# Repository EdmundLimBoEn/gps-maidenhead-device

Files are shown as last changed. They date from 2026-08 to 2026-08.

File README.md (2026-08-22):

# Maidenhead Pocket Locator

Open hardware and software for a compact GNSS-powered six-character Maidenhead
locator. The product requirements and validation gates live in [PLAN.md](PLAN.md).

## Current status

The development source tree covers RP2040 firmware and host tests, a
Tk/serial configurator with profiles and UF2 recovery, KiCad engineering sources
and manufacturing workflow, a parametric enclosure with printable exports, and
assembly/validation documentation.

This is **not yet a physically validated product release**. Ordering and public
distribution remain gated on the frozen BOM/quote, reviewed manufacturing exports,
prototype bring-up, and measured acceptance evidence listed in
[the release checklist](docs/manufacturing/RELEASE_CHECKLIST.md) and
[evidence index](docs/testing/TEST_EVIDENCE.md). No claim is made here that the
weather, battery, GNSS, off-current, thermal, or cost gates have passed.

## Development

```sh
cmake -S firmware -B .build/firmware
cmake --build .build/firmware
ctest --test-dir .build/firmware --output-on-failure

python -m venv .venv
. .venv/bin/activate
python -m pip install -e './configurator[dev]'
pytest configurator/tests
python -m ruff check configurator tools
python -m ruff format --check configurator tools
python -m maidenhead_configurator

bash firmware/tests/pico_stub_compile.sh
python3 hardware/manufacturing/preflight.py
python3 tools/export_enclosure.py
python3 tools/validate_enclosure.py --require-openscad
python3 tools/check_docs.py
python3 tools/release_preflight.py
```

To build an RP2040 UF2, install the Pico SDK and set its location:

```sh
PICO_SDK_PATH=/path/to/pico-sdk \
  cmake -S firmware -B .build/firmware-pico -DPOCKET_LOCATOR_BUILD_RP2040=ON
cmake --build .build/firmware-pico
```

The GUI starts against a simulator by default. A physical device uses
newline-delimited JSON over USB CDC; each configuration write includes a fresh
15-year named-zone transition table. Profiles remain location-free and portable.

## Manufacturing and safety

Do not order or distribute from an arbitrary working tree. Generate artifacts from
a tagged revision, complete [the five-unit order package](docs/manufacturing/ORDER_PACKAGE.md),
and follow the [assembly](docs/assembly/ASSEMBLY.md) and
[test procedures](docs/testing/TEST_PROCEDURES.md).

The [mechanical interface contract](enclosure/INTERFACES.md) and
[cost research snapshot](docs/manufacturing/COST_RESEARCH.md) make the remaining
fit and landed-cost unknowns explicit. Neither is a manufacturing sign-off.

Use only the released protected LiPo and charger configuration. The device is not
an emergency locator, navigation instrument, tracker, or immersion-rated product.
Do not charge it while wet or leave it charging in a hot vehicle.

## Licensing

Firmware and configurator code are GPL-3.0-or-later. Hardware and mechanical
sources are CERN-OHL-S-2.0. Documentation is CC-BY-SA-4.0. See [LICENSES](LICENSES/README.md).

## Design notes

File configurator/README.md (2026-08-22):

# Configurator

Requires Python 3.11 or newer, Tkinter, and a data-capable USB cable. Install the
project and start the simulated-device prototype with:

```sh
python -m pip install -e .
python -m maidenhead_configurator
```

Some Linux distributions package Tkinter separately (commonly `python3-tk`). The
Windows install automatically includes the `tzdata` package used by `zoneinfo`.
The configurator never derives a time zone from device coordinates; it sends
transitions for the IANA zone selected by the user.

Profiles are versioned JSON. They intentionally omit coordinates, transient GNSS
diagnostics, and the generated time-zone table. Applying a profile or pressing
**Validate and apply** regenerates and sends a compact 15-year transition table
from the host's current IANA database. The supplied
`profiles/factory-default.json` is a portable starting profile.

For a physical device, click **Refresh USB**, select the RP2040 CDC port, and
click **Connect**. The Device screen reports firmware, hardware, configuration
health, and non-persistent diagnostics. If discovery finds nothing, verify that
the cable carries data and that local serial-port permissions allow access.

Normal firmware installation validates the RP2040 UF2, requires a profile
backup, enters ROM BOOTSEL, copies without unsupported filesystem metadata, and
waits for the boot volume to disappear before reconnecting. If application
firmware cannot start, use **Install using BOOTSEL recovery…** after attaching
the device with its internal BOOTSEL control held. ROM volumes are recognized
by their `RPI-RP2` name or `INFO_UF2.TXT`, including Windows drive roots.

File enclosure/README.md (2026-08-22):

# Enclosure engineering source

The parametric OpenSCAD design has an 88 × 44 mm front profile and a calculated
34.5 mm assembled depth. Automated checks confirm those source/export dimensions;
they do not prove component fit, sealing, print tolerance, or RF performance.

The 1.5 mm shell provides 2 mm nominal edge clearance around the current
81 × 37 mm engineering PCB. A 3 mm mating flange provides a real 1 × 0.7 mm
continuous seal groove for nominal 1 mm silicone cord (30% calculated compression)
while retaining 0.5 mm PCB insertion clearance per side.
The lid has a 71 × 25 × 1.1 mm window recess and a
66 × 16 mm through-aperture, leaving a 2.5/4.5 mm continuous seal land. The source also
contains reinforced hard-stop lands, recessed boot apertures, USB plug,
battery rails, antenna frame, and heat-set-insert bosses.

Connector, button, LCD mounting, board retention, antenna orientation, and cable
interfaces remain release-blocking until the exact purchased parts and a shared
datum model pass [the interface contract](INTERFACES.md). The generated shape is
an engineering fit-check, not a production-ready weather-resistant enclosure.

Print structural parts in PETG or ASA, not PLA. Print button boots and the USB
plug in a UV-resistant flexible material. Use a 1 mm clear polycarbonate window
cut to 71 × 25 mm and continuously seal it to the recessed land.

```sh
python3 ../tools/export_enclosure.py
python3 ../tools/validate_enclosure.py --require-openscad
(cd exports && sha256sum -c SHA256SUMS)
```

Before releasing a print, confirm the selected LCD, cell, PCB, coax bend radius,
window, gasket cord, tactile switches, and USB connector against physical samples.
The current battery rails locate a fit dummy but are not a released positive
retainer; that feature remains blocked on the exact cell and Z stack.
After any parameter/source change, regenerate all exports and their checksum file.

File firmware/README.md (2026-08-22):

# Pocket Locator firmware

The firmware uses one C++ core for native tests and the RP2040 UF2. Hardware
code is deliberately isolated under `src/{board,display,gnss,storage,device}`;
the Maidenhead, NMEA, session, layout, configuration validation, and protocol
modules remain host-testable.

## Native tests

```sh
cmake -S firmware -B build/firmware-host
cmake --build build/firmware-host
ctest --test-dir build/firmware-host --output-on-failure
```

## Build a UF2

Install the Raspberry Pi Pico SDK, then either export `PICO_SDK_PATH` or pass
it to CMake.

```sh
cmake -S firmware -B build/rp2040 \
  -DPOCKET_LOCATOR_BUILD_HOST_TESTS=OFF \
  -DPOCKET_LOCATOR_BUILD_RP2040=ON \
  -DPICO_SDK_PATH=/path/to/pico-sdk
cmake --build build/rp2040
```

The resulting `pocket_locator_rp2040.uf2` is an RP2040 ROM-BOOTSEL image.
The application command `reboot_to_bootloader` uses `reset_usb_boot`; the
internal physical BOOTSEL switch remains the recovery mechanism if firmware
does not start.

## Rev-A electrical contract

`include/pocket_locator/board/pins.hpp` is the single source of MCU pin
assignments. The current pin map is deliberately named, not inferred from a
schematic, so production routing must be checked against it before releasing a
PCB revision.

| Function | GPIO | Notes |
| --- | ---: | --- |
| LOCATE / OFF | 2 / 3 | Active-low switches using internal pull-ups and 25 ms polling debounce |
| POWER_HOLD | 4 | High holds the system latch; firmware releases it on shutdown |
| LCD 5 V enable | 5 | Active-high TPS61023 enable; remains low in USB idle |
| LCD RS, E, D4–D7 | 6–11 | 3.3 V outputs into the SN74LVC8T245PWR A-side; LCD R/W is grounded |
| LCD backlight | 12 | PWM into the logic-level backlight MOSFET |
| GP-02 UART TX/RX | 16 / 17 | UART0 at 9,600 8N1; RX is receiver output |
| GNSS enable | 18 | Active-high switched receiver enable; firmware waits 5 ms for the rail before assigning UART pins |
| Battery divider | 26 / ADC0 | 100 kΩ / 100 kΩ (2:1) with 100 nF; firmware waits 30 ms (6× the 5 ms RC constant) before sampling |
| USB VBUS / charger status | 19 / 20 | VBUS active-high; USB device pull-up is enabled only while VBUS is present; charger status active-low/open-drain |
| Battery-divider enable | 21 | Active-high only for the ADC sampling window |

The selected power circuit must permit USB VBUS to sustain the MCU after
`POWER_HOLD` is released. `POWER_HOLD` must not be connected to any reset or
watchdog output. The GP-02 is explicitly disabled in USB idle, and no GNSS
coordinates are written to flash.

On a battery start, `POWER_HOLD` remains low until the software has observed
the continuous LOCATE hold for one second. A LOCATE already held while the MCU
comes out of reset is timestamped at boot (`0 ms`), so the accepted-session
deadlines retain the physical press edge as closely as the latch power-up
latency permits; they are never rebased to the end of debounce or hold checks.

## Flash configuration reservation

`FlashConfigStore` uses the final two physical flash sectors (8 KiB) on the
2 MiB production flash: inactive sector erase/write, XIP read-back/CRC
verification, then a one-way commit marker. The application image must remain
below that reserved tail. Check the generated `.elf`/map in release CI and do
not change the configured flash size without revisiting this reservation.

The linker asserts that the image ends before the reserved region. A power loss
at any write phase leaves the previous committed record valid. Factory reset
commits defaults through the same inactive-slot transaction; it never erases
application firmware or destroys the prior record before defaults verify.

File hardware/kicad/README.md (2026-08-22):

# Hardware design source

SPDX-License-Identifier: CERN-OHL-S-2.0

This directory contains the revision-A *engineering* KiCad source for the
Maidenhead Pocket Locator.  It is deliberately a source-controlled design,
not by itself a claim that an assembled product has been validated: the selected
LCD, patch antenna, cell and enclosure still require physical fit checks. No RF,
power, charger or thermal measurement has been performed on assembled hardware.

`design.yaml` is a review summary of the electrical architecture and constraints;
the component/pin contract is embedded in `generate_kicad.py`. The generator
writes the legacy schematic and cache while preserving the authoritative routed
PCB. Passing `--force-placement` explicitly replaces the PCB with its
deterministic unrouted placement. The source set contains:

* `maidenhead-pocket-locator.sch` — deterministic legacy Eeschema source;
* `maidenhead-pocket-locator.kicad_sch` — the committed modern KiCad source,
  synchronized from the legacy source with KiCad and used for PDF/netlist exports;
* `maidenhead-pocket-locator.kicad_pcb` — the authoritative routed 4-layer,
  81 x 37 mm board with edge connectors, test points and controlled RF/USB
  net classes. The default manufacturing preflight requires zero DRC errors,
  zero unconnected items, filled inner planes, no signal tracks on In1, and
  only the length-bounded `LCD_RS_3V3`, `LOCATE_N`, `QSPI_SCLK`, and
  `QSPI_SD2` crossovers on In2.

The generated board is useful for electrical/mechanical review and routing
iteration. It must not be sent to a fabricator until the
release checklist passes.  `../manufacturing/export.sh` runs the KiCad CLI
exports and DRC when KiCad is installed.

## Regenerate and inspect

```sh
python3 hardware/kicad/generate_kicad.py
# After an intentional electrical edit, open the legacy .sch in the pinned KiCad
# version, save the converted modern .kicad_sch, and run preflight to compare them.
# Only when intentionally restarting layout:
python3 hardware/kicad/generate_kicad.py --force-placement
python3 hardware/manufacturing/preflight.py --source-only
python3 hardware/manufacturing/preflight.py
kicad hardware/kicad/maidenhead-pocket-locator.kicad_pro
```

The source-only command is a diagnostic aid. CI and manufacturing exports use
the strict default command; it must pass before manufacturing exports are
accepted.

The board datum is the lower-left outside corner.  LCD/window centre is
`(40.5, 18.5)`.  The antenna is an enclosure-mounted patch, not a PCB
component; its 50-ohm route ends at J4.  Keep the top-wall patch projection
clear of copper and parts as documented in `../RF_AND_LAYOUT.md`.

The controlled stack is F.Cu signal/power, In1 uninterrupted GND reference,
In2 predominantly 3V3 power distribution, and B.Cu signal/GND. In2 carries only
the under-7 mm LCD RS, under-4 mm LOCATE, and under-6 mm QSPI SCLK/SD2
crossovers allowlisted by preflight. USB and GNSS RF stay on outer copper over
In1; the short QSPI inner runs also reference the uninterrupted In1 plane. Obtain
the fabricator's impedance calculation before release; nominal
trace widths in the source are starting values, not a substitute for a coupon.
Ordinary logic uses 0.15 mm traces and 0.50/0.20 mm through-vias. Dense QSPI
fanout uses 0.10 mm traces and local 0.46/0.20 mm standard through-vias; confirm
the 0.13 mm annular ring with the selected fabricator. The edge rule
is 0.20 mm for the unavoidable short escapes at J1, SW1 and SW2; confirm both
capabilities in the selected board quote.

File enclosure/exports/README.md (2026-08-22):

# Generated enclosure exports

Generate STL files from `../source/enclosure.scad` with the commands in the
enclosure README. Generated meshes are revision artifacts; the OpenSCAD source
and its parameters remain authoritative.

`SHA256SUMS` covers the four printable meshes, window-cut profile, and generated
assembly preview. Run
`python3 ../../tools/validate_enclosure.py --require-openscad` to verify dimensions,
mesh validity, and agreement with freshly rendered source. `assembly.png` remains
an orientation preview and is not dimensional evidence.

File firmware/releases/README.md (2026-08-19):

# Firmware release artifacts

`pocket_locator_rp2040.uf2` is built from the repository firmware source with
the Raspberry Pi Pico SDK. Rebuild it with the commands in `firmware/README.md`
and verify its RP2040 family identifier before distribution.

Verify the tracked artifact with `sha256sum -c firmware/releases/SHA256SUMS`
from the repository root.

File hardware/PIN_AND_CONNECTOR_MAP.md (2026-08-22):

# Pin and connector map — Revision A

SPDX-License-Identifier: CC-BY-SA-4.0

This table is the electrical contract between the board and
`firmware/include/pocket_locator/board/pins.hpp`. A PCB release must reconcile
it against the *purchased* GP-02, LCD and charger datasheets; a named net is
not evidence that a symbol pin is correct.

## RP2040 assignment

| RP2040 pin/function | Net | Connected hardware | Electrical notes |
|---|---|---|---|
| GPIO2 | `LOCATE_N` | SW1 | Active low; local pull-up to 3V3; the same actuator starts the hardware latch through an isolated transistor path. |
| GPIO3 | `OFF_N` | SW2 | Active low; local pull-up to 3V3. |
| GPIO4 | `POWER_HOLD` | Q2 gate/control | Assert high only after one-second LOCATE validation. Must default low/Hi-Z at reset. |
| GPIO5 | `LCD_POWER_EN` | U5 EN | Active high; USB idle keeps the 5 V LCD rail disconnected. |
| GPIO6 | `LCD_RS_3V3` | U6 A0 | U6 B0 -> J3 pin 4. |
| GPIO7 | `LCD_E_3V3` | U6 A1 | U6 B1 -> J3 pin 6. |
| GPIO8 | `LCD_D4_3V3` | U6 A2 | U6 B2 -> J3 pin 11. |
| GPIO9 | `LCD_D5_3V3` | U6 A3 | U6 B3 -> J3 pin 12. |
| GPIO10 | `LCD_D6_3V3` | U6 A4 | U6 B4 -> J3 pin 13. |
| GPIO11 | `LCD_D7_3V3` | U6 A5 | U6 B5 -> J3 pin 14. |
| GPIO12 / PWM | `BL_PWM` | Q3 gate | Q3 is LCD backlight low-side switch; do not drive LCD logic supply with PWM. |
| GPIO16 / UART0 TX | `GNSS_RX` | U7 UART input | MCU output to receiver input. |
| GPIO17 / UART0 RX | `GNSS_TX` | U7 UART output | Receiver output to MCU input. |
| GPIO18 | `GNSS_EN` | U7 enable/load switch | Default low; does not supply GNSS backup power during shutdown. |
| GPIO19 | `VBUS_PRESENT` | VBUS sense divider | Series/diode isolated: VBUS must never power 3V3 through this pin. |
| GPIO20 | `CHG_N` | U3 CHG output | Open drain/active low; RCHGPU1 is the explicit 100 kΩ logic pull-up, in parallel with the separately current-limited RCHG1/LED indicator branch. |
| GPIO21 | `BAT_SENSE_EN` | Q5/Q4 divider switch | Pulse high, wait for the 100 nF ADC node to settle, sample, then return low. |
| GPIO26 / ADC0 | `BAT_ADC` | switched divider | Q4 isolates BAT whenever GPIO21 is low or 3V3 is absent; calibrate before setting battery icon thresholds. |
| QSPI CSn (ROM BOOTSEL) | `BOOTSEL_N` | SW3 to GND | Physical recovery switch only. Never connect to ordinary GPIO or LCD. |
| RUN | `RUN_N` | SW4 to GND / TP | Reset; pull-up and capacitor must follow RP2040 reference circuit. |
| XIN / XOUT | `XIN` / `XOUT` | X1 ABM8-272-T3 | 15 pF C0G loads; XOUT passes through 1 kΩ RXTAL1 to `XOUT_XTAL` to limit crystal drive. |
| SWDIO / SWCLK | `SWDIO`, `SWCLK` | TP pads | Test pads, no production debug connector required. |

Unused GPIOs are not routed to external connectors. Keep their reset pulls as
recommended by the RP2040 hardware design guide.

## External connectors and LCD header

| Connector / pin | Net | Direction / purpose |
|---|---|---|
| J1 USB-C A4/A9/B4/B9 | `VBUS_RAW` | 5 V receptacle input; F1 creates protected `VBUS` for charger and sensing. No PD source capability. |
| J1 USB-C A6/B6 | `USB_DP_CONN` | USB 2.0 D+ into D1; D1 output and RUSB1 create `USB_DP` at RP2040. |
| J1 USB-C A7/B7 | `USB_DM_CONN` | USB 2.0 D− into D1; D1 output and RUSB2 create `USB_DM` at RP2040. |
| J1 CC1, CC2 | `CC1`, `CC2` | Independent 5.1 kΩ Rd to GND. |
| J1 shield and GND pins | `GND` | Tie to ground plane at connector; final EMI treatment requires review. |
| J2 pin 1 | `BAT` | Protected cell positive to BQ24074 BAT. BQ24074 OUT, rather than the raw cell, creates `SYS_RAW`. |
| J2 pin 2 | `CHG_TS` | Cell thermistor to BQ24074 TS; TH1 is alternative only. |
| J2 pin 3 | `GND` | Cell return. |
| J3 pin 1 / 2 | `GND` / `5V_LCD` | LCD logic supply. |
| J3 pin 3 | `LCD_VO` | Contrast potentiometer/divider, 5 V-safe. |
| J3 pin 4 / 6 | `LCD_RS` / `LCD_E` | From U6 B0/B1. |
| J3 pin 5 | `GND` | LCD R/W permanently low. |
| J3 pins 7–10 | `GND` | LCD D0–D3 unused in 4-bit mode. |
| J3 pins 11–14 | `LCD_D4`–`LCD_D7` | From U6 B2–B5. |
| J3 pin 15 / 16 | `LCD_BL_A` / `LCD_BL_K` | Positive through verified current limit; Q3 PWM low side. |
| J4 centre / shell | `GNSS_RF_50R` / `GND` | u.FL to enclosure patch; centre trace has 50-ohm grounded-coplanar target. |

## Required test points

`VBUS`, `BAT`, `SYS_RAW`, `3V3`, `5V_LCD`, `GND`, `POWER_HOLD`, `GNSS_TX`,
`GNSS_RX`, `SWDIO`, `SWCLK`, `RUN_N`, and `BOOTSEL_N` shall be present as
labelled, probe-accessible pads. Test pad placement must preserve the GNSS
RF keep-out and never turn a debug probe ground lead into the RF return path.

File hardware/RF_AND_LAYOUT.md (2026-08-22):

# RF, placement, and routing constraints — Revision A

SPDX-License-Identifier: CC-BY-SA-4.0

The GP-02 to patch assembly is the principal reception risk. This document
defines constraints for the design; it does not certify antenna performance.
If the purchased GP-02 requires a different matching topology, its datasheet
supersedes this document and the schematic/PCB must be revised together.

## GNSS path

1. U7 RF pin to J4 is a continuous 50-ohm grounded coplanar waveguide on the
   outer layer. Calculate width, clearance, and via fence pitch from the
   *ordered* JLCPCB stack-up; do not copy a generic 50-ohm width.
2. Do not place a series DC-block or matching component unless required by the
   purchased receiver/patch data. Preserve a footprint land pattern for an
   optional 0402 series component and a shunt-to-ground component only when
   the actual reference circuit permits it.
3. Keep this route as short as practical, with no stubs, neck-downs, vias, or
   90-degree corners. Ground vias flank the line at a pitch no greater than
   one-tenth of the effective wavelength in board material; refine after the
   selected stack-up is known.
4. Keep the u.FL launch and its shell vias continuous with the RF ground. The
   coax may not be sharply folded, trapped under a screw boss, or routed across
   the 5V inductor, USB pair, LCD flex/header, or RP2040 crystal.
5. The 25 x 25 mm patch is mounted ceramic-face upward below the enclosure top
   wall. No battery, LCD PCB, screw, metallic paint, copper, or other conductor
   is allowed directly above it. Its ground-plane requirement is a purchased
   antenna-data-sheet gate, not an assumed rectangle of copper.

## Noise separation and plane strategy

- Use a solid, uninterrupted B.Cu ground plane except for approved RF
  clearances. Route low-speed signals on F.Cu where possible; never slit the
  return path beneath USB D+/D− or the RF line.
- Put U5/L1/C11 together on the side opposite U7/J4. The switch node is the
  smallest possible copper island and is surrounded by a ground return. Do not
  pour copper under the inductor unless its datasheet allows it.
- Keep the RP2040 crystal and its load capacitors adjacent to U1, with no USB,
  PWM, boost, or RF trace below/through the crystal keep-out.
- Put D1 at J1 before the USB pair enters the board. Route D+/D− as a short,
  matched differential pair over continuous ground, avoiding stubs at any
  optional series parts.
- PWM backlight current returns directly to the 5V boost output capacitor,
  not through the GNSS ground region. Verify the effect with satellite tests
  at backlight-off, dim, full, USB-active, and LCD-update conditions.

## Placement and board mechanics

The nominal four-layer PCB is 81 x 37 mm inside an approximately 88 x 44 mm front
enclosure. J1 is centred on the left wall; the LCD is rear-mounted at the
window datum; U7/J4 occupy the upper-right RF zone; power conversion occupies
the lower-left/centre away from RF. The final enclosure source controls exact
boss, gasket, window, button, and antenna locations.

Before ordering, import the enclosure datum model and verify these minimum
checks: board-to-wall clearance, USB shell/cap clearance, LCD glass/window
gap, battery pouch and lead bend radius, patch clearance, button travel,
light-pipe alignment, screw-boss keep-outs, and test-pad access with a probe.

## Four-layer release rules

- Board edge, holes, PCB thickness, and the explicit 0.20 mm copper-to-edge
  minimum are confirmed against the fabricator capability selected for the
  quote. The 0.20 mm rule is required by the short escapes from the three
  edge-mounted parts (J1, SW1 and SW2); do not order from a process with a
  larger finished-copper edge requirement.
- All component footprints are from a reviewed local library or vendor drawing
  and include pin-1/polarity markings. Never fabricate from the placeholder
  outline blocks in the early generated board.
- Assign net classes before routing: RF controlled impedance, USB differential
  pair, battery/charger high current, LCD boost/backlight, and ordinary logic.
- Ordinary logic uses 0.15 mm traces and 0.50/0.20 mm finished through-vias;
  the selected four-layer process must explicitly support those dimensions.
  USB, RF, and power keep their dedicated net-class geometry and are not
  reduced to the ordinary-logic values to escape congestion.
- Run ERC and DRC with zero unreviewed errors, inspect Gerbers in an independent
  viewer, and use the fabrication checklist in `manufacturing/`.

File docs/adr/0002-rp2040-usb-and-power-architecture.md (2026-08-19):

# ADR-0002: Use RP2040, USB-C, power-path charging, and hardware shutdown

- Status: accepted
- Date: 2026-08-19

## Context

The device needs cross-platform USB configuration, end-user firmware updates, operation while charging, eight-hour outing endurance, and enough retained charge for one check after a year of storage. Custom firmware is explicitly allowed.

## Decision

Use an RP2040 with native USB and external QSPI flash. USB-C carries 5 V charging and USB 2.0 data. Use a BQ24074-class power-path charger and a low-leak hardware soft latch that physically removes switched system power. USB VBUS may keep the MCU in a dark, GNSS-off configuration state.

Normal and recovery updates use RP2040 ROM BOOTSEL and UF2. Normal firmware can reboot itself into BOOTSEL. If application firmware cannot run, removing the rear cover and holding a labelled internal BOOTSEL switch while attaching USB forces recovery without electrically multiplexing a runtime button onto QSPI flash control.

## Consequences

- Updates are recoverable without a debug probe.
- Shutdown current depends mainly on charger, load-switch, and protection leakage rather than MCU sleep quality.
- The PCB needs additional flash, USB protection, latch logic, and careful power sequencing.
- Unsigned custom firmware can replace all application behavior; the GUI must warn and back up configuration first.

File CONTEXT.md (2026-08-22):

# Domain Glossary

## Product terms

**Maidenhead Pocket Locator**  
The complete portable device described in `PLAN.md`.

**Locator**  
The six-character Maidenhead representation calculated from the current WGS-84 position, for example `OJ11XH`. Use “six-character,” not “six-digit,” because four positions are letters.

**Current fix**  
A receiver-declared valid GNSS position obtained during the present check session. A previously acquired position is never treated as current.

**Check session**  
The interval beginning at the initial `LOCATE` button-down edge of a subsequently accepted one-second hold, and ending when `OFF`, the shutdown deadline, or a failure releases the hardware power hold.

**Single-fix mode**  
A check session that stops active GNSS tracking after the first valid position is displayed.

**Tracking mode**  
A check session that continues processing GNSS fixes and considers a display update every five seconds.

**Grid stabilization**  
The rule requiring two consecutive valid fixes in the same new locator before the displayed locator changes.

**Acquisition timeout**  
Maximum duration from the initial button-down edge of an accepted `LOCATE` hold to a valid GNSS fix. Factory default: 120 seconds.

**Dim deadline**  
Time from the initial button-down edge of an accepted `LOCATE` hold at which the backlight changes to configured dim brightness. Factory default: 60 seconds.

**Shutdown deadline**  
Time from the initial button-down edge of an accepted `LOCATE` hold at which the hardware power hold is released. Factory default: 120 seconds, except for the three-second terminal `NO GPS` message.

**Factory settings**  
The safe configuration restored by a five-second two-button hold. The factory named time zone is `Asia/Singapore`.

## Hardware terms

**Power hold**  
The MCU signal that keeps the switched system rails enabled after the physical `LOCATE` press starts the device.

**Hard shutdown**  
The state in which switched rails for MCU, GNSS, LCD, and sensing are physically removed rather than relying only on MCU sleep.

**Power path**  
Charger behavior that independently powers the system and charges the cell, allowing normal operation while USB is connected without corrupting charge termination.

**Internal patch**  
The passive ceramic GNSS antenna mounted under the enclosure's top wall and connected to the GP-02 by short coax and u.FL/I-PEX.

**Front profile**  
The enclosure width and height seen from the LCD face. The frozen engineering envelope is 88 × 44 mm, with total depth limited to 35 mm.

**Weather goal**  
Survival of drizzle, dust, and incidental sand exposure. It is not an IP rating and does not include immersion.

## Software terms

**Display builder**  
The configurator screen where battery, time, date, separators, and static-text fields are arranged with a live 16-character preview.

**Configuration profile**  
A versioned, human-readable JSON representation of user settings that can be saved and applied to multiple devices. It never contains position history.

**Named zone**  
An IANA time-zone identifier such as `Asia/Singapore` or `America/New_York`. V1 receives its future offset transitions from the host configurator; it does not infer the zone from coordinates.

**Normal update**  
A GUI-driven firmware update that asks running firmware to enter RP2040 ROM BOOTSEL and then installs a selected UF2.

**Recovery update**  
A firmware update entered by opening the rear cover and holding the internal `BOOTSEL` control while connecting USB, independent of application firmware.

**V1**  
The first public hardware, firmware, enclosure, and configurator release that passes the acceptance criteria in `PLAN.md`.

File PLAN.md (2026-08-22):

# Maidenhead Pocket Locator — Build Plan

Status: development sources and automated electrical/layout checks are complete and clean; manufacturing remains blocked on exact-part Z-stack and physical-overlay validation, exact-part sourcing, a landed quote, prototypes, and measured acceptance evidence
Target batch: 5–20 devices  
Hard landed-cost target: **US$30 or less for every unit, including the first five**  
Licensing goal: reciprocal open source

## 1. Product definition

Build a compact, battery-powered amateur-radio companion that obtains its current position from GNSS and displays the corresponding six-character Maidenhead locator on a blue-backlit 16×2 character LCD.

The device is intended for desks, portable radio outings, and use in occupied vehicles. It should feel like a useful radio tool and a fun object to give to other operators. It is not a navigation device, emergency beacon, location logger, or formally rated waterproof product.

### Default display

```text
GRID: OJ11XH
▰ 14:35 19/08
```

The battery glyph is illustrative. The firmware will use one of the LCD's custom-character slots for a four-level battery icon.

### Primary interaction

1. Hold `LOCATE` for one second.
2. The device powers up and immediately shows `ACQUIRING GPS` rather than a cached grid.
3. On a valid fix, it calculates and displays the six-character locator and flashes the backlight briefly.
4. By default, the backlight dims 60 seconds after the original `LOCATE` button-down edge.
5. By default, the device shuts down 120 seconds after that same button-down edge.
6. Holding `OFF` for one second shuts it down early.
7. Holding both buttons for five seconds restores factory settings after an on-screen countdown.

Once the one-second hold is accepted, all timers are backdated to the initial `LOCATE` button-down edge, including time spent validating the hold and acquiring GNSS. If the default two-minute acquisition timeout expires without a fix, show `NO GPS` for three seconds and shut down; this terminal message is the only default exception to the 120-second power-off deadline.

### Configuration modes

The Python configurator selects one of two GNSS behaviors:

- `single_fix`: acquire one valid position for the session, display it, and stop active GNSS tracking.
- `tracking`: continue processing fixes and update the locator every five seconds until shutdown.

In tracking mode, a new locator must appear in two consecutive valid fixes before replacing the displayed locator. This prevents grid flicker near a subsquare boundary.

### Non-goals for V1

- No location history or logging; coordinates are discarded at shutdown.
- No stale-location fallback.
- No external GNSS antenna connector.
- No automatic geographic time-zone detection.
- No Wi-Fi, Bluetooth, mobile app, buzzer, lanyard, or belt clip.
- No immersion rating or untested IP claim.
- No on-device settings menus.

## 2. Acceptance criteria

V1 is complete only when all of the following pass:

| Area | Acceptance criterion |
|---|---|
| Locator | Correct uppercase six-character Maidenhead output from WGS-84 latitude/longitude, including boundary and antimeridian tests |
| Cold fix | At least 9 of 10 open-sky cold-start trials produce a valid grid within the configured default two-minute timeout |
| Stability | A new grid appears only after two consecutive valid fixes agree |
| Battery outing | Survives an eight-hour test with four full two-minute checks per hour and retains enough charge for one additional check |
| Stored unit | Electronics shutdown current is at most 10 µA at 25 °C; after realistic one-year cell self-discharge, the design budget still allows at least one location check |
| Controls | Each button requires a deliberate one-second hold; bag pressure and short taps do not latch the device on |
| USB | Charging, configuration, and normal location operation work while connected |
| Firmware recovery | An interrupted or invalid update can be recovered through the internal RP2040 ROM BOOTSEL control without a debugger |
| Configuration | Settings persist across shutdown, reject corruption, and can be saved/restored as profiles |
| Weather goal | Passes the drizzle and sand procedures in section 8 with no internal ingress or control failure |
| Thermal | Operates at 40 °C ambient and inhibits charging when the battery sensor is too warm |
| Mechanical | Front profile remains approximately LCD-sized (engineering source: 88 × 44 mm); total depth does not exceed 35 mm |
| Cost | Quoted landed cost is no more than US$30 per finished unit when ordering the first five |

The locator definition and test vectors should follow the ADIF WGS-84 encoding: positions 1–2 use `A–R`, 3–4 use `0–9`, and 5–6 use `A–X`. See the [ADIF Maidenhead definition](https://adif.org.uk/315/ADIF_315.htm#Maidenhead_Locators).

## 3. Hardware plan

### 3.1 Architecture

```mermaid
flowchart LR
    USB[USB-C] --> CHG[Power-path charger]
    CELL[Protected 1S LiPo] <--> CHG
    CHG --> LATCH[Low-leak load switch / soft latch]
    LOCATE[LOCATE button] --> LATCH
    LATCH --> RAIL3[3.3 V rail]
    LATCH --> BOOST[5 V LCD boost]
    RAIL3 --> MCU[RP2040]
    RAIL3 --> GPS[GP-02 GNSS]
    GPS -->|UART NMEA| MCU
    PATCH[Internal passive patch] -->|short coax + u.FL| GPS
    MCU -->|PWM| BOOST
    MCU --> LEVEL[SN74LVC8T245 level shift]
    LEVEL --> LCD[Blue 1602 LCD]
    OFF[OFF button] --> MCU
    MCU -->|power hold / release| LATCH
```

### 3.2 Candidate parts and rationale

These are design candidates, not permission to order. Freeze exact manufacturer part numbers only after schematic review, stock confirmation, physical layout, and the cost gate.

| Function | V1 candidate | Reason / constraint |
|---|---|---|
| MCU | RP2040 + 2 MB QSPI flash | Low-cost native USB, adequate UART/PWM/ADC, mature C/C++ SDK, and UF2 recovery in immutable ROM. The [RP2040 datasheet](https://datasheets.raspberrypi.com/rp2040/rp2040-datasheet.pdf) documents the USB controller and ROM bootloader. |
| GNSS receiver | Ai-Thinker GP-02 | Cost-down choice; multi-constellation receiver with UART NMEA and passive/active antenna support. Use the [manufacturer specification](https://docs.ai-thinker.com/_media/gp-02_specification.pdf) as the schematic authority. |
| GNSS antenna | Internal passive L1 ceramic patch with short coax and u.FL/I-PEX plug | Allows the patch to mount beneath the top wall and face the sky without enlarging the LCD-like front profile. Final antenna must provide documented dimensions, cable loss, ground requirements, and operating temperature. |
| GNSS fallback | Quectel L86-M33 | Use only if the GP-02 plus remote patch fails reception tests. Its integrated patch is lower RF-integration risk but materially more expensive. |
| LCD | HD44780/ST7066-compatible blue-backlit 16×2 module, nominal 80 × 36 mm | Matches the requested Arduino-kit appearance. Freeze a 5 V part with measured backlight current and published outline drawing. A representative module is up to 13.5 mm thick; see [Winstar WH1602B](https://www.winstar.com.tw/products/lcd-display/character-lcd-display-module/lcd-display-16x2.html). |
| LCD level translation | SN74LVC8T245PWR, write-only 4-bit LCD bus | Its dual rails translate RP2040 3.3 V outputs to the 5 V LCD domain. Strap direction A→B, hold output-enable active, ground unused A inputs, tie LCD `R/W` low, and use fixed command delays. |
| LCD supply | TPS61023 set to 5 V | Efficient boost converter with true disconnect and about 0.1 µA shutdown current. See [TI TPS61023](https://www.ti.com/product/TPS61023). |
| Backlight control | Logic-level MOSFET driven by MCU PWM | Provides normal/dim brightness sliders, success flash, and full backlight cutoff. Verify the selected LCD includes or receives a safe LED current-limiting resistor. |
| Charger / power path | BQ24074 | Supports simultaneous system use and charging, input limiting, thermal regulation, and battery NTC monitoring. See [TI BQ24074](https://www.ti.com/product/BQ24074). Do not replace it with a charger lacking load sharing merely to save cost. |
| Battery | Replaceable protected 1S LiPo, preliminary 1,000 mAh, keyed JST-PH-class connector | Capacity is intentionally provisional. Freeze it after measuring the selected LCD and a complete two-minute session. Use a reputable protected cell; prevent reverse insertion mechanically and electrically. |
| Battery indication | Switched high-value divider into MCU ADC | Four-level icon only. Enable the divider only while measuring; calibrate thresholds against the assembled unit under a known light load. |
| Charge indication | Charger status output to a red LED behind a sealed light pipe | LED is on while charging and off when complete or unplugged. The LCD remains dark merely because USB is attached. |
| USB-C | USB 2.0 device connector with CC resistors, ESD protection, and tethered sealing plug | Must work with USB-A-to-C and C-to-C data cables. USB provides charging, CDC configuration, and firmware update. |
| Buttons | Two side-mounted tactile switches under matching recessed elastomer actuators | Both require a one-second hold. Actuators should feel like a radio PTT rather than exposed PCB buttons. |

### 3.3 Power behavior

Use a hardware soft-latch rather than relying on MCU deep sleep:

- A `LOCATE` press temporarily enables the post-charger system load switch.
- The MCU asserts `POWER_HOLD` only after the press remains valid for one second.
- Releasing `POWER_HOLD` removes power from the MCU, GNSS, LCD boost, level shifter, and sensor divider.
- USB VBUS independently enables the MCU so the configurator is always reachable. USB insertion must not light the LCD or start GNSS by itself.
- While USB is present, `OFF` returns the firmware to USB-idle mode because external power intentionally keeps the configurator alive.
- The charger and cell protection remain connected during shutdown. Their combined battery drain, plus load-switch leakage, must meet the 10 µA electronics target.
- Do not maintain GNSS backup power for a full year; accept a cold start after long storage in exchange for lower drain.
- Add a power-on-reset supervisor if testing shows unreliable latch startup or flash corruption near battery cutoff.

Preliminary charging configuration:

- USB input: 5 V only; no USB Power Delivery negotiation.
- Input limit: 500 mA unless thermal testing supports more.
- Charge current: select after the exact cell is chosen; never exceed its datasheet rating.
- Battery NTC: use the cell's third wire when available, otherwise mount a board thermistor firmly against the cell pouch.
- Charging should stop outside the cell supplier's permitted temperature window; the 40 °C ambient requirement is not permission to charge an overheated cell.

### 3.4 PCB

- Design in KiCad as a four-layer board: F.Cu/B.Cu carry signals, In1 is an
  uninterrupted ground reference, and In2 distributes power with only four
  length-bounded crossovers: LCD RS (under 7 mm), LOCATE (under 4 mm), and
  QSPI SCLK/SD2 (under 6 mm). USB and RF remain on the outer layers. The two-layer
  cost-first attempt was rejected because routing fragmented critical return
  paths for USB and GNSS RF.
- Let JLCPCB assemble all SMD parts, including RP2040, GP-02, charger, converters, USB-C, ESD, and level shifting.
- Keep hand work to the LCD/header, battery plug-in, antenna plug-in, actuator installation, and enclosure assembly.
- Place labelled test points for `VBUS`, `BAT`, charger output, `3V3`, `5V_LCD`, `GND`, `POWER_HOLD`, UART TX/RX, SWDIO, SWCLK, RUN, and BOOTSEL.
- Route the GP-02 RF output to u.FL as a short 50 Ω grounded coplanar trace using JLCPCB's actual stack-up. Add ground stitching vias and obey the receiver and connector keep-outs.
- Keep the GNSS/RF area away from the 5 V boost inductor, LCD edge, USB data pair, and RP2040 crystal.
- Place USB-C, LED light pipe, button switches, LCD header, and battery connector from the CAD assembly—not by schematic convenience.
- Add polarity, pin-1, connector, and button labels to silkscreen.
- Export manufacturing files, schematic PDF, interactive BOM, pick-and-place, and JLC assembly drawings from versioned source.

### 3.5 Enclosure

Target envelope: approximately LCD-sized and **no more than 35 mm deep**. The engineering enclosure is **88 × 44 × 34.5 mm** because the original 85 × 41 mm concept left no physical land for both the 81 × 37 mm PCB and a continuous gasket. Depth absorbs the battery, PCBA, sealing, and antenna orientation.

Construction:

- Two-piece screw-fastened FDM enclosure in PETG or ASA; do not use PLA for the field version.
- Continuous perimeter gasket in a designed compression groove. Use hard stops so screws cannot crush or extrude the gasket.
- Recessed clear polycarbonate LCD window with its own gasket or continuous closed-cell adhesive seal; do not expose the LCD glass directly.
- Matching recessed elastomer button boots or a single molded membrane over the two tactile switches.
- Tethered USB-C port plug and a gasketed/light-pipe charging indicator.
- Internal ceramic patch adhered beneath the top wall, ceramic face toward the sky, with no battery, display PCB, fastener, metallic coating, or copper immediately above it.
- Replaceable battery retained without puncture risk, foam compression on the pouch, or strain on its leads.
- Captive or retained threaded inserts where practical; repeated battery access must not destroy FDM screw holes.
- No lanyard or clip features.

Weather claim: “designed for drizzle, dust, and incidental sand exposure; not for immersion.” A future machined enclosure should preserve the PCB, control, antenna, window, and gasket interfaces.

### 3.6 Cost gate

The following is a target allocation, not a quote. It includes allocated setup and shipping but excludes the builder's labor and borrowed tools, matching the agreed parts-cost definition.

| Cost group | Target per unit |
|---|---:|
| LCD | $2.00–3.50 |
| GP-02 + internal patch/coax | $3.50–5.00 |
| RP2040, flash, clock, USB | $1.75–2.75 |
| Charger, load switch, 3.3 V/5 V power, level shifting, protection, passives | $3.50–5.00 |
| Protected LiPo + connector | $3.00–5.00 |
| PCB and PCBA allocation | $3.00–5.00 |
| Enclosure, window, gasket, actuators, screws, light pipe | $2.50–4.00 |
| Allocated shipping, setup, extended-part, and fixture charges | $2.00–4.00 |
| **Target total** | **$21.25–34.25** |

Because the high estimate exceeds the requirement, cost control is a formal milestone:

1. Prepare the complete five-unit JLCPCB cart and every non-JLC purchase before ordering anything.
2. Include taxes, shipping, setup, assembly, stencil/fixture, spare-part minimums, and enclosure consumables.
3. Divide the total by five finished devices; do not hide unused minimum-quantity parts outside the calculation.
4. If the total exceeds $150, reduce cost and requote. Do not order on the assumption that later units will amortize it.
5. Cost-down order: consolidate JLC basic parts, source LCD/cell/window hardware locally, simplify non-safety mechanical hardware, then compare compatible documented GNSS/antenna parts.
6. Do **not** cost down by removing cell protection, NTC monitoring, power-path/load sharing, USB ESD, the gasket/window, or firmware recovery.

## 4. Firmware plan

### 4.1 Stack and modules

Use the Raspberry Pi Pico C/C++ SDK with CMake. Keep hardware drivers thin and put all conversion, layout, configuration, and state behavior in host-testable C++ modules.

Suggested modules:

```text
firmware/
  app/             state machine and event loop
  board/           pins, clocks, ADC, power hold, boot entry
  gnss/            UART transport, NMEA parsing, fix validity
  maidenhead/      pure WGS-84 coordinate-to-locator conversion
  display/         1602 driver, glyphs, PWM, screen composition
  layout/          validated 16-character field renderer
  time/            GNSS UTC and configured named-zone transitions
  config/          schema, defaults, migration, CRC, atomic storage
  usb/             CDC protocol, diagnostics, bootloader command
  tests/            native and device tests
```

### 4.2 State machine

| State | Entry / behavior | Exit |
|---|---|---|
| `OFF` | Hardware rails absent | `LOCATE` begins enabling power, or USB supplies configuration power |
| `PRESS_CHECK` | Count a continuous one-second `LOCATE` hold; if accepted, use the initial button-down edge as all timer epoch | Short release → power drops; valid hold → `ACQUIRING` |
| `USB_IDLE` | CDC/configuration active; LCD and GNSS off | `LOCATE` → `ACQUIRING`; USB removal → power drops unless held |
| `ACQUIRING` | Show `ACQUIRING GPS`; parse only current live fix data | Valid fix → `DISPLAY_FIX`; timeout → `NO_GPS`; `OFF` → shutdown |
| `DISPLAY_FIX` | Show `GRID: XX00XX`, battery, time/date layout; flash backlight | Single-fix mode stops GNSS; tracking mode continues; dim deadline → `DIMMED` |
| `DIMMED` | Use configured dim PWM; continue selected GNSS mode | Shutdown deadline or `OFF` → shutdown; valid tracking fix may update grid |
| `NO_GPS` | Show failure for three seconds | Release power hold |
| `FACTORY_RESET` | Both buttons held five seconds with countdown | Atomically restore defaults and restart |

Debounce inputs in software and ensure watchdog recovery cannot accidentally hold power forever. After accepting the hold, start both default deadlines from its initial button-down edge, not one second later and not from first fix.

### 4.3 Fix validity and grid calculation

- Accept only a receiver-declared valid 2D/3D fix with valid latitude, longitude, UTC date, and UTC time.
- Reject out-of-range, NaN, truncated, checksum-failed, and stale NMEA sentences.
- Keep coordinates in RAM only.
- Convert from WGS-84 latitude/longitude to exactly six characters: field letters, square digits, subsquare letters.
- Normalize output to uppercase (`OJ11XH`).
- Define behavior explicitly at `+90`, `-90`, and `±180` degrees to avoid array overflow; clamp only as specified by the test oracle.
- In tracking mode, stage a changed grid and commit it only after the next valid fix returns the same new grid. A fix in the currently displayed grid cancels the candidate.
- Parse at the receiver's normal output rate but render/update no more often than every five seconds in tracking mode.

### 4.4 Display and configuration schema

Factory defaults:

| Setting | Default |
|---|---|
| Top row | `GRID: {grid6}` |
| Bottom row | battery icon, one space, `HH:MM`, one space, `DD/MM` |
| Named time zone | `Asia/Singapore` |
| Clock | 24 hour, seconds off |
| GNSS mode | `single_fix` |
| Tracking render interval | 5 seconds |
| Acquisition timeout | 120 seconds |
| Dim deadline | 60 seconds from `LOCATE` press |
| Shutdown deadline | 120 seconds from `LOCATE` press |
| Normal brightness | 100% logical level, capped by hardware-safe PWM |
| Dim brightness | 20% logical level |

Supported bottom-row building blocks:

- Battery glyph: four levels plus charging state if useful while the LCD is intentionally on.
- Time: 12/24 hour and seconds independently selectable.
- Date presets: `DD/MM`, `MM/DD`, `DDMMM`, and `YYYY-MM-DD`.
- Arbitrary static text, including callsigns.
- Literal spaces and a small set of separators.

The GUI must prevent any rendered variant from exceeding 16 characters. Validate worst cases such as `12:59:59 PM`, not only the current preview value.

Store configuration in two versioned flash slots with sequence number and CRC. Write the inactive slot, verify it, then mark it current. On invalid or unsupported configuration, boot safe factory defaults and report the error over USB.

### 4.5 Named time zones

V1 does not infer a zone from coordinates. The GUI uses Python's IANA `zoneinfo` data to let the user choose a named zone and sends a compact table of future UTC offset transitions for that one zone.

- Generate at least 15 years of transitions from the configuration date.
- Store the zone name, generation date, expiry year, initial offset, abbreviations, and transitions.
- Zones without daylight-saving transitions, including the `Asia/Singapore` default, remain simple.
- After the table expires, continue with the last known offset but report `timezone_refresh_required` in USB diagnostics.
- Reconfiguring or applying a profile regenerates the transition table from the host's current time-zone database.
- Automatic geographic zone detection remains a future firmware feature and must not be implied by V1 UI copy.

### 4.6 Diagnostics

Expose read-only USB diagnostics without retaining location history:

- Firmware and hardware revision.
- Configuration schema version and CRC health.
- Battery ADC reading and derived level.
- Charger/input state and onboard temperature.
- GNSS state, current satellite/fix-quality fields, and latest coordinates only while the session is active.
- Shutdown-current measurement cannot be self-reported because the MCU is unpowered; document the external test.

## 5. Python configurator plan

### 5.1 Stack

- Python 3.11 or newer.
- Tkinter for the cross-platform window.
- `pyserial` for USB CDC discovery and communication.
- Standard-library `zoneinfo` for named zones; document how Windows users obtain current IANA data if their Python installation lacks it.
- Custom in-window drag-and-drop behavior so arranging fields does not depend on platform-native file drag APIs.

Support Windows, macOS, and Linux equally. Users are expected to install Python; packaged executables are not a V1 requirement.

### 5.2 GUI screens

1. **Device** — connection state, firmware/hardware version, battery, settings health, and diagnostics.
2. **Display builder** — draggable battery/time/date/text blocks, properties panel, and exact 16-character live preview.
3. **Behavior** — single-fix/tracking selection, acquisition timeout, dim/shutdown timers, and normal/dim brightness.
4. **Time** — named-zone chooser, 12/24-hour selector, seconds toggle, and date format.
5. **Profiles** — create, save, load, import, export, compare, and apply versioned JSON profiles.
6. **Firmware** — select a UF2, validate compatibility, back up the current profile, update, reconnect, and verify the reported version.
7. **Factory reset** — explicit confirmation and post-reset verification.

### 5.3 USB protocol

Use newline-delimited, versioned JSON over USB CDC for readability and community implementation.

Every request contains `protocol_version`, `request_id`, and `command`. Every response echoes the request ID and returns either structured data or a stable error code. Required commands:

- `hello`
- `get_info`
- `get_config`
- `validate_config`
- `set_config`
- `get_diagnostics`
- `factory_reset`
- `reboot_to_bootloader`

Set operations are transactional: validate in RAM, persist atomically, read back, and only then report success. Cap message size and reject unknown or malformed input without destabilizing the device.

### 5.4 Profiles

- Human-readable JSON with profile schema version, display layout, behavior, time settings, and optional notes.
- Do not include coordinates or transient GNSS diagnostics.
- Migrate older profile versions explicitly; never silently discard fields.
- Show a diff before applying a profile to a connected device.
- Regenerate named-zone transitions at apply time rather than treating old transition tables as permanent profile data.

### 5.5 Firmware updates and recovery

Normal flow:

1. User selects any RP2040 UF2 file; community/custom images are allowed and signatures are not required.
2. GUI checks UF2 structure and RP2040 family compatibility. It warns, rather than pretending custom code is trusted.
3. GUI exports the current configuration profile.
4. GUI commands the device into ROM BOOTSEL, detects the mounted `RPI-RP2` volume, copies the UF2, waits for reconnect, and verifies the firmware-reported result when supported.
5. Official firmware migrates or preserves the reserved configuration region when compatible. A custom UF2 may overwrite or ignore it, so the profile backup is mandatory.

Recovery flow:

- Remove the gasketed rear cover, hold a clearly labelled internal `BOOTSEL` tact switch, and attach USB-C. This enters ROM recovery independent of application firmware without adding a leak-prone exterior hole or risky multiplexing onto `OFF`.
- The GUI detects the ROM volume and performs the same copy operation.
- Expose labelled BOOTSEL/RUN test pads beside the switch as a final manufacturing fallback.

Raspberry Pi documents BOOTSEL as read-only ROM that cannot be overwritten by application software; see the [Pico recovery documentation](https://www.raspberrypi.com/documentation/microcontrollers/pico-series.html#resetting-flash-memory).

## 6. Repository and licensing

```text
/
  PLAN.md
  CONTEXT.md
  LICENSES/
  docs/
    adr/
    assembly/
    testing/
  hardware/
    kicad/
    bom/
    manufacturing/
  enclosure/
    source/
    exports/
  firmware/
  configurator/
  tools/
```

Licenses:

- Firmware and Python configurator: `GPL-3.0-or-later`.
- PCB and mechanical source: `CERN-OHL-S-2.0`.
- Documentation: `CC-BY-SA-4.0`.
- Include SPDX identifiers in source files and a clear contribution/licensing section in the README.

These reciprocal licenses implement the requirement that distributed derivatives remain open. Review third-party fonts, libraries, footprints, and CAD models before inclusion; prefer compatible permissive or reciprocal dependencies.

## 7. Implementation phases

### Phase 0 — deterministic software core

- Establish repository, licenses, CI, formatting, and host test harness.
- Implement and exhaustively test Maidenhead conversion before touching hardware.
- Implement NMEA parsing against captured and synthetic streams.
- Implement state machine, grid stabilization, layout rendering, configuration schema, and profile schema as host tests.
- Build a GUI prototype with a simulated device transport.

Exit: conversion/state/layout/profile tests pass on Windows, macOS, and Linux CI.

### Phase 1 — electrical design and quote

- Select exact LCD, passive patch, cell, actuators, connectors, gasket, and charger configuration.
- Measure or obtain trustworthy worst-case LCD backlight current before fixing cell capacity and charge current.
- Draft schematic, power budget, off-current budget, RF layout, PCB outline, and connector placement.
- Review against every manufacturer reference circuit.
- Create preliminary enclosure stack-up and verify the approximately LCD-sized, ≤35 mm-deep envelope.
- Produce complete five-unit landed quote.

Exit: schematic review complete, dimensional stack fits, predicted shutdown current ≤10 µA, and five-unit total ≤$150. Otherwise redesign and requote.

### Phase 2 — PCB and enclosure release

- Finish placement with a shared PCB/enclosure datum model.
- Route, run ERC/DRC, inspect Gerbers, verify footprints against physical drawings, and generate assembly outputs.
- Print an unpopulated enclosure fit-check or dimensional mock-up before PCBA release.
- Order five assembled boards only after the cost gate passes.
- Print one enclosure first; keep the remaining four until fit corrections settle.

Exit: order reviewed from generated artifacts by checklist, not only inside KiCad.

### Phase 3 — first-board bring-up

- Use a borrowed multimeter. Begin with battery disconnected and a current-limited/protected USB source.
- Inspect polarity, solder bridges, QFN alignment, connectors, and antenna lead before power.
- Check ground continuity and absence of shorts; then verify VBUS, charger output, 3.3 V, and 5 V rails.
- Load a minimal firmware in this order: power hold, USB, buttons, LCD, ADC, then GNSS.
- Confirm charger behavior and temperature cutoff before connecting the production cell.
- Confirm BOOTSEL recovery before installing the gasketed enclosure.

Exit: one complete unit passes all basic functional and safety checks without rework wires. If rework is necessary, decide whether the remaining boards are safe to populate/use or require a PCB revision.

### Phase 4 — validation

- Run the complete test matrix in section 8.
- Measure actual active current at full and dim backlight, single-fix mode, and tracking mode.
- Recalculate capacity and one-year standby budget with measured data.
- Record antenna orientation and ground-plane effects; invoke the L86 fallback only if placement/tuning cannot make GP-02 pass.
- Use test results to update enclosure clearances, gasket compression, firmware defaults, and assembly instructions.

Exit: all acceptance criteria pass and remaining risks are documented.

### Phase 5 — public V1 release

- Tag reproducible firmware and configurator releases.
- Publish KiCad, CAD source, exact BOM with substitutes, Gerbers, assembly files, firmware UF2, Python setup instructions, profiles, test evidence, and assembly guide.
- Include prominent LiPo, heat, charging, water-resistance, and non-emergency-device warnings.
- Build and give out the remaining units only from the validated revision.

## 8. Test matrix

### Software

- Known Maidenhead vectors from an independent reference implementation.
- Randomized property tests across valid WGS-84 coordinates.
- Exact field/square/subsquare boundaries, poles, equator, prime meridian, and antimeridian.
- NMEA checksums, missing fields, contradictory RMC/GGA validity, stale sentences, and UART truncation.
- Two-fix grid stabilization, including `A → B → A`, `A → B → B`, and invalid fixes between candidates.
- Button bounce, short press, exactly one-second press, simultaneous press, and stuck button.
- Timer ordering and invalid configuration such as shutdown earlier than dim.
- Every display field combination and worst-case 16-character width.
- DST forward/back transitions, zones without DST, half/quarter-hour offsets, transition-table expiry, and `Asia/Singapore` reset default.
- Power loss during each phase of configuration write.
- Malformed/oversized USB requests and reconnect during operations.
- Firmware update interruption before copy, during copy, and during reconnect.

### GNSS and RF

- Ten true cold starts outdoors with backup power discharged.
- Warm repeated checks during an eight-hour outing.
- Face-up, handheld, desk-angle, and vehicle-dashboard orientations.
- Near-window indoor behavior is recorded but is not a pass/fail promise.
- Compare GP-02 patch placement alternatives before changing receiver.
- Verify the 5 V boost, USB, and LCD refresh do not measurably degrade satellite acquisition.

### Power and battery

- Validate charger current, termination, power-path operation, and charge LED.
- Operate GNSS/LCD while charging and while the battery is absent if the charger design permits it.
- Confirm NTC hot/cold inhibition by safely simulating sensor resistance.
- Measure shutdown current at full, half, and low cell voltage.
- Run 32 two-minute sessions spread over eight hours, with factory brightness/timers, followed by one reserve check.
- Verify low-battery behavior does not repeatedly reboot or corrupt flash.
- Treat the one-year criterion as an electronics drain budget plus the selected cell maker's self-discharge/aging data; do not claim it solely from an accelerated bench test.

### Mechanical and environmental

- Verify LCD, PCB, antenna, cell, wires, connector bend radius, window, and gasket fit without forced compression.
- Cycle each button at least 1,000 times on a sacrificial/prototype enclosure and check boot sealing afterward.
- Open and reseal the battery compartment at least ten times.
- Drizzle test: controlled spray from multiple directions for ten minutes, USB cap installed, with absorbent indicator paper inside; no visible ingress.
- Sand test: expose seams/buttons/cap to dry beach-like sand, brush clean, then verify actuation and opening without grains reaching electronics.
- Soft-ground drop tests from normal hand height in multiple orientations.
- Operate at 40 °C ambient; inspect enclosure deformation, LCD readability, GNSS behavior, cell temperature, and charger inhibition.
- Do not test immersion because V1 does not claim it.

### Cross-platform configurator

- Clean Python setup on current Windows, macOS, and Linux.
- Device discovery with multiple serial ports present.
- Apply/read-back profiles, Unicode rejection or transliteration for unsupported LCD characters, and missing time-zone data handling.
- Normal and recovery firmware updates on all three systems.
- Clear errors for charge-only USB cables and permission-denied serial ports.

## 9. Principal risks and mitigations

| Risk | Mitigation / decision gate |
|---|---|
| First-five landed cost exceeds $30 each | Complete carts before ordering; GP-02 is primary; iterate sourcing/part consolidation until total is ≤$150 |
| Internal passive patch has weak reception | Top-wall placement, short controlled RF path, orientation tests; L86-M33 fallback only after placement experiments |
| 35 mm depth is insufficient | Physical stack model and printed fit-check before PCBA order; front width/height stay fixed while internal mounts are revised |
| Blue LCD dominates power | Measure exact module; hardware current limit and PWM; resize cell before freeze |
| One-year storage misses a check | True hardware cutoff, ≤10 µA measured electronics drain, protected reputable cell, no maintained GNSS backup |
| FDM enclosure leaks | Designed gasket compression, separate window seal, button membrane, USB plug, spray/sand test; no IP claim |
| Charging at high temperature damages cell | BQ24074 NTC monitoring, cell-adjacent thermistor, conservative current, explicit no-hot-car-charging warning |
| Firmware update appears to brick device | Hardware BOOTSEL gesture and immutable RP2040 ROM recovery; profile backup before update |
| Named-zone rules become stale | Host-generated 15-year transition table and diagnostic expiry flag |
| Custom firmware breaks configuration compatibility | Allow it by design, warn clearly, export profile first, and preserve ROM recovery |

## 10. Decision summary

The detailed rationale is recorded under `docs/adr/`.

- A deliberately simple two-button locator replaces an on-device menu.
- The LCD always shows the current six-character locator, never a stale one.
- USB-C is the single charging, configuration, and update connection.
- A Python/Tkinter GUI provides profiles and a drag-and-drop 16-character row builder.
- RP2040 and compiled C/C++ provide deterministic firmware and recoverable updates.
- GP-02 plus a remote internal passive patch is the V1 cost architecture; L86-M33 is the reception fallback.
- A hardware power latch and power-path charger support one-year storage intent and operation while charging.
- The enclosure preserves the LCD front outline by growing only to a maximum 35 mm depth.
- V1 is drizzle/sand resistant, not immersion-rated.
- All distributed derivatives must remain open through reciprocal licenses.

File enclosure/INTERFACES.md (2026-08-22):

# Mechanical interface contract

This is the release-blocking datum contract between PCB and enclosure source. It
records required coordinates without claiming that the current engineering PCB,
footprints, or purchased parts satisfy them.

## Datum and envelope

- Enclosure XY origin: lower-left corner of the 88 × 44 mm front profile, viewed
  from the display side. Z=0 is the outside face of the clear window.
- PCB outline: 81 × 37 × 1.6 mm, centered at enclosure `(3.5, 3.5)` in XY.
- Nominal outer-edge margin is 3.5 mm and shell-to-PCB interior clearance is 2 mm
  on every side. The 82 × 38 mm flange opening leaves 0.5 mm insertion clearance
  per side. These values must be revised
  from measured print and board tolerances; it is not an interference-fit spec.
- Maximum assembled outside depth: 35 mm; source target: 34.5 mm.
- The nominal Winstar WH1602B outline is 80 × 36 × 13.5 mm with 75 × 31 mm
  mounting-hole pitch and 66 × 16 mm viewing area. Centering it maps those holes
  to the four enclosure centers below. Verify the exact ordered suffix against
  the [manufacturer drawing](https://www.winstar.com.tw/uploads/files/cce99cb4f21c2bd9362dfadcc10c188a.pdf).

## Frozen XY centers for the routing datum

| Interface | PCB coordinate (mm) | Enclosure coordinate (mm) | Gate |
|---|---:|---:|---|
| USB-C mating-face center | left edge `(0, 14)` | left wall `(0, 17.5)` | Exact connector body/plug clearance still gated |
| LOCATE actuator tip | right edge `(81, 10)` | right wall `(88, 13.5)` | TL1014BF160QG drawing/boot stack still gated |
| OFF actuator tip | right edge `(81, 27)` | right wall `(88, 30.5)` | 17 mm center spacing |
| Mount 1, Ø2.7 NPTH | `(3, 3)` | `(6.5, 6.5)` | M2.5 hardware |
| Mount 2, Ø2.7 NPTH | `(78, 3)` | `(81.5, 6.5)` | M2.5 hardware |
| Mount 3, Ø2.7 NPTH | `(3, 34)` | `(6.5, 37.5)` | M2.5 hardware |
| Mount 4, Ø2.7 NPTH | `(78, 34)` | `(81.5, 37.5)` | M2.5 hardware |

The board-space coordinates are frozen so PCB routing cannot drift. Enclosure
coordinates are their (+3.5,+3.5) translation; the shell grew from the original
85 × 41 concept because that envelope left no material for a real gasket groove.
The USB footprint origin, connector body, switch footprint bodies, and all Z
coordinates must still come from exact drawings and the shared stack. Do not treat
the table as permission to order. The exact Winstar LCD,
USB receptacle, side switches, window, gasket, cell, antenna/coax, and fasteners
must be overlaid from manufacturer drawings and then checked with physical samples.

## Known unresolved stack constraints

- The 80 × 36 mm LCD nearly fills the front profile. Its mounting holes, header,
  bezel depth, glass keep-out, and enclosure fasteners must use one verified model.
- A 25 × 25 × 4 mm patch cannot be described merely as “under the top wall.” Its
  ceramic face direction and a metal/copper-free volume must be explicit in CAD.
- The battery, LCD body, populated PCB, antenna, coax bend, and wire/connector
  service loops need a single Z stack with tolerances. Nominal bounding boxes alone
  are insufficient because their allowed volumes currently overlap.
- The source has battery positioning rails but no frozen positive vertical/end
  retainer. Add a removable, non-compressing retainer only after the exact protected
  cell and PCB Z stack are measured; the pouch must never be used as a spring.
- USB and button openings must follow the final edge-mounted footprints. Moving
  openings independently from the PCB is prohibited after the datum is frozen.

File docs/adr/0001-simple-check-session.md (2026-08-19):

# ADR-0001: Use a two-button check-session interaction

- Status: accepted
- Date: 2026-08-19

## Context

The device must be quick to use alongside a radio, survive long storage, and remain understandable when given to another operator. On-device customization would conflict with the 16×2 display, weather-sealed controls, and simple “survival-kit” character.

## Decision

Use two matching recessed elastomer controls: `LOCATE` and `OFF`. Both require a continuous one-second hold. `LOCATE` begins a time-bounded check session; `OFF` ends it. A five-second hold of both controls restores factory settings. All other settings require USB and the Python configurator.

The device never displays a cached location. It shows `ACQUIRING GPS` until a current valid fix exists, then `GRID: XX00XX`. A successful fix flashes the backlight. Once a one-second hold is accepted, default dim and shutdown deadlines are 60 and 120 seconds from its initial button-down edge.

## Consequences

- Operation is obvious and accidental bag activation is less likely.
- The enclosure needs only two sealed actuators.
- Configuration requires a computer and data-capable USB cable.
- A cold start may consume the entire default session and return `NO GPS`; users can lengthen the timeout in the GUI.

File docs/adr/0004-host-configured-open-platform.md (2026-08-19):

# ADR-0004: Put customization in an open Python desktop tool

- Status: accepted
- Date: 2026-08-19

## Context

Recipients should be able to rearrange the status row, change time/date presentation, select named time zones, adjust brightness and timers, switch GNSS behavior, reuse profiles, and install future or community firmware. The device itself has only two controls.

## Decision

Build a Python 3.11+ Tkinter configurator for Windows, macOS, and Linux. Communicate using versioned newline-delimited JSON over USB CDC. Provide a drag-and-drop display builder with exact 16-character preview, versioned JSON profiles, diagnostics, factory reset, and GUI-managed UF2 updates.

Use reciprocal licensing: GPL-3.0-or-later for software, CERN-OHL-S-2.0 for hardware/CAD, and CC-BY-SA-4.0 for documentation.

## Consequences

- Recipients must install Python and use a data-capable cable.
- Profiles make a 5–20 device gift batch practical.
- Named-zone transition data can be prepared on the host without placing a global geographic/time-zone database on the MCU.
- Third-party dependencies and contributed derivatives must remain license-compatible.

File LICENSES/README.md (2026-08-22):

# Licenses

- Software (`firmware/`, `configurator/`, `tools/`):
  [GNU GPL 3.0 or later](GPL-3.0-or-later.txt)
- Hardware and mechanical source (`hardware/`, `enclosure/`):
  [CERN Open Hardware Licence Version 2 - Strongly Reciprocal](CERN-OHL-S-2.0.txt)
- Documentation (`PLAN.md`, `CONTEXT.md`, `README.md`, `docs/`):
  [Creative Commons Attribution-ShareAlike 4.0](CC-BY-SA-4.0.txt)

SPDX identifiers in individual source files are authoritative for their scope.

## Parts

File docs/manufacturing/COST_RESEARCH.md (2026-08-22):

# Five-unit cost research snapshot

Snapshot date: **2026-08-21 UTC**. Quantity basis: five finished units. Currency:
USD. Destination, shipping method, tax, duties, assembly stock class, and coupons
are intentionally unselected. This is attributable research, **not a cart, landed
quote, or cost-gate pass**.

## Exact-part storefront subtotal

The prices below are public LCSC storefront prices visible on the snapshot date.
They cover only seven exact engineering-BOM lines and use the applicable 1+ or 5+
tier. JLCPCB assembly inventory/prices can differ from the LCSC storefront.

| BOM part | Qty | Observed unit price | Five-unit extension | Source |
|---|---:|---:|---:|---|
| RP2040 | 5 | $0.9930 | $4.9650 | [LCSC C2040](https://www.lcsc.com/product-detail/Microcontroller-Units-MCUs-MPUs-SOCs_span-style-background-color-ff0-Raspberry-span-Pi-RP2040_C2040.html) |
| W25Q16JVUXIQ | 5 | $0.5066 | $2.5330 | [LCSC C2843335](https://lcsc.com/product-detail/NOR-FLASH_Winbond-Elec_C2843335.html) |
| BQ24074RGTR | 5 | $2.1335 | $10.6675 | [LCSC C54313](https://www.lcsc.com/product-detail/battery-management_ti-bq24074rgtr_C54313.html) |
| TPS63802DLAR | 5 | $1.0846 | $5.4230 | [LCSC C2845237](https://www.lcsc.com/product-detail/DC-DC-Converters_Texas-Instruments-TPS63802DLAR_C2845237.html) |
| TPS61023DRLR | 5 | $0.2673 | $1.3365 | [LCSC C919459](https://www.lcsc.com/product-detail/dc-dc%20converters_texas%20instruments_tps61023drlr_C919459.html) |
| SN74LVC8T245PWR | 5 | $0.3893 | $1.9465 | [LCSC C27643](https://www.lcsc.com/product-detail/Translators-Level-Shifters_Texas-Instruments_C27643.html) |
| USB4105-GF-A | 5 | $1.0330 | $5.1650 | [LCSC C3020560](https://www.lcsc.com/product-detail/C3020560.html) |
| **Observed subtotal** | | | **$32.0365** | Excludes every line below |

The GP-02 manufacturer listing was out of stock at LCSC in the available snapshot,
so no price is recorded. Substitution is not assumed.

## Public JLCPCB service floors

The production design uses four layers so USB and GNSS RF have an uninterrupted
In1 ground reference while In2 distributes 3.3 V around the under-7 mm LCD RS,
under-4 mm LOCATE, and under-6 mm QSPI SCLK/SD2 crossovers; USB and RF stay on
outer layers. These are the only preflight-allowlisted signal tracks on an
inner layer. The earlier two-layer cost
target was rejected after routing fragmented the ground return. For comparison,
JLCPCB advertises a standard two-layer board no larger than 100 × 100 mm at a
promotional fabrication price starting at $2 for five boards. Its published 2025
economic-PCBA schedule lists an $8 setup fee, $1.50 stencil fee, $0.0016 per
automated joint, $3 per extended component feeder, and separate component costs.
These are pricing rules, not a project quote: [PCB order guide](https://jlcpcb.com/help/article/how-do-i-place-an-order),
[assembly price schedule](https://jlcpcb.com/help/article/pcb-assembly-price).

The bare-board + setup + stencil public floor is therefore $11.50 before joints,
feeders, components, X-ray, hand assembly, shipping, tax, or duties. No coupon is
counted. The automated Gerber and footprint-contract gates are clean, but a complete
quote still requires the signed-off GUI ERC, exact ordered-part overlays, and populated
supplier/JLC carts.

## Unquoted release-blocking lines

- Remaining semiconductors, crystal, inductors, protection, passives, connectors,
  switches, LCD header, and charge LED
- GP-02, passive patch/coax, exact blue LCD, protected 3-wire LiPo, and harnesses
- PCB assembly joints, extended feeders, QFN inspection, excess/minimum parts
- Window, seal, gasket cord, boots/membrane, USB plug, inserts, screws, light pipe,
  PETG/ASA and flexible filament, failed-print allowance
- All supplier/JLC shipping, tax, import duty, payment/FX fees, setup and consumables

The authoritative gate remains a saved, date-stamped five-unit cart total of no
more than $150. Research subtotals must never be filled into that gate as landed cost.

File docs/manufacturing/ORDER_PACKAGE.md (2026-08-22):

# Five-unit order package

Prepare this package from a tagged, reviewed revision before placing any order.
The source tree contains engineering artifacts; this document is a controlled
checklist for turning them into an order without silently bypassing a gate.

## Include

- KiCad project, schematic PDF, Gerbers, drill, IPC/netlist, engineering BOM,
  matched SMD assembly BOM/CPL, interactive BOM, assembly drawing, and DRC/ERC
  reports generated from the same commit.
- Exact manufacturer part numbers, approved substitutes, stock snapshots, and
  physical drawings for the LCD, patch/coax, cell, switches, connectors, window,
  gasket, screws, and inserts.
- JLCPCB five-board/assembly cart export plus every external supplier cart.
- The dated [cost-research snapshot](COST_RESEARCH.md), superseded by saved carts
  for the exact released revision; research prices are not landed quote evidence.
- Enclosure source, STL exports, print material/setting sheet, and an unpopulated
  fit-check record.
- Firmware UF2 hash, configurator version/profile, assembly guide, bring-up
  procedure, and recovery instructions.

## Cost calculation

```
five_unit_total = JLC PCB + assembly + setup + stencil/fixture + shipping + tax
                + all non-JLC minimum quantities + enclosure consumables
per_finished_unit = five_unit_total / 5
```

The order gate passes only when `five_unit_total <= US$150`. Do not exclude spare
minimum quantities, shipping, taxes, fixture charges, or enclosure consumables.
Store the rendered carts and totals with the release evidence.
Record destination country, currency/FX rate, quote expiry, shipping service,
tax/duty treatment, and whether any coupon or new-customer promotion was applied.

## Sign-off

| Role | Name | Date | Commit / revision |
|---|---|---|---|
| Electrical review |  |  |  |
| RF / layout review |  |  |  |
| Mechanical fit review |  |  |  |
| Cost gate |  |  |  |
| Order authorization |  |  |  |

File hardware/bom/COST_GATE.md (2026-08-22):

# Five-unit cost gate

Do not order until every cell below has a supplier quote including tax, shipping,
minimum quantities, assembly/setup fees, and consumables. The passing total is
US$150 or less for five finished devices.

| Group | Supplier / part | Extended landed cost | Evidence date |
|---|---|---:|---|
| LCD | TBD | | |
| GNSS and antenna | TBD | | |
| MCU, USB, and flash | TBD | | |
| Power and protection | TBD | | |
| Battery | TBD | | |
| PCB/PCBA | TBD | | |
| Enclosure hardware | TBD | | |
| Shipping/setup/consumables | TBD | | |
| **Five-unit total** | | **BLOCKED until quoted** | |
| **Per finished unit (total / 5)** | | **BLOCKED until quoted** | |

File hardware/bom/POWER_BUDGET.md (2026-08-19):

# Power budget

SPDX-License-Identifier: CC-BY-SA-4.0

This worksheet sizes Revision A; it is not a measurement or battery-life
claim. The exact LCD, protected cell, GP-02 lot and board leakage remain
physical release gates.

## Rail architecture

`BQ24074.OUT` is the only source of `SYS_RAW`. The protected cell connects only
to `BQ24074.BAT`; Q1 is a signal MOSFET that can source the TPS63802 enable pin,
not a load-path bypass. TPS63802 generates regulated 3.3 V across the useful
1S-cell range. USB VBUS diode-ORs into its enable so CDC remains available,
while GPIO5 and GPIO18 leave the true-disconnect LCD boost and GNSS load switch
off in USB idle.

## Battery-off leakage budget (USB absent)

| BAT-connected item | Conservative allocation (uA) | Verification gate |
|---|---:|---|
| BQ24074 BAT/OUT power-path standby | 2.0 | Replace with applicable datasheet maximum and measure through BAT |
| TPS63802 disabled VIN leakage | 0.6 | TI maximum through 85 °C; measure at 3.0/3.7/4.2 V |
| Q1 start PMOS and Q2 gate network | 1.2 | Include D2/D3/D4 and contamination over temperature |
| Q4/Q5 disabled battery-divider switch | 1.2 | Confirm BAT is isolated from divider and unpowered ADC |
| Remaining BAT-referred leakage / board margin | 2.0 | Measure assembled, cleaned board |
| **Predicted allocation** | **7.0** | **Not a pass result; every unit must measure ≤10 uA at 25 °C** |

The cell protection circuit, cell self-discharge and ageing are outside the
electronics-only 10 µA criterion but remain part of the one-year reserve
calculation. At 7 µA, electronics alone consume about 61.3 mAh/year. No storage
claim may use this arithmetic without worst-case cell-maker data and a measured
reserve session.

## Active-session worksheet

Sizing assumptions: 3.7 V cell, TPS63802 90% efficiency at the relevant load,
TPS61023 83%, GP-02 45 mA at 3.3 V, RP2040/flash 35 mA at 3.3 V, LCD logic
2 mA and representative backlight 25 mA at 5 V.

| Mode | Estimated battery current | Required measurement |
|---|---:|---|
| Acquiring, full LCD | `(3.3*(45+35)/0.90 + 5*(2+25)/0.83)/3.7` = 124 mA | True cold acquisition, full backlight |
| Display, full LCD | `(3.3*35/0.90 + 5*27/0.83)/3.7` = 79 mA | Valid-fix display |
| Display, dim 20% | `(3.3*35/0.90 + 5*7/0.83)/3.7` = 46 mA | PWM average and peak |
| USB idle | 0 mA battery-discharge target | Verify charger/power-path direction with cell present and absent |

Thirty-two 120-second worst-case acquisition sessions consume roughly 132 mAh
before cell ageing, cold-start variation and low-voltage converter loss. Final
capacity and charge current remain blocked on measured loads and the selected
cell datasheet.

## Measurement method

1. With USB absent, measure BAT current after hard shutdown at 4.2, 3.7 and
   3.0 V after transients settle.
2. Record active current for acquire, full/dim display, tracking, USB idle and
   charging. Capture PWM current with adequate bandwidth.
3. Safely simulate the frozen NTC hot/cold limits and verify charge inhibition,
   termination and power-path operation.
4. Record exact BOM revisions, firmware, ambient temperature and instruments in
   `docs/testing/`; never promote calculated values to acceptance evidence.

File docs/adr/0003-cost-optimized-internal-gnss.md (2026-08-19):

# ADR-0003: Use GP-02 with a remote internal passive patch for V1

- Status: accepted
- Date: 2026-08-19

## Context

The first five complete units must each land below US$30. A proven integrated-patch Quectel L86-M33 consumes too much of that budget and constrains antenna orientation behind the LCD-sized front face.

## Decision

Use a JLCPCB-assembled Ai-Thinker GP-02 receiver and connect it through a short controlled-impedance trace, u.FL/I-PEX, and short coax to a passive ceramic patch mounted beneath the enclosure's top wall. Keep the device sealed with no external antenna port.

Retain L86-M33 as a documented fallback only if the primary design fails its open-sky acquisition criterion after placement and noise experiments.

## Consequences

- Expected receiver cost falls by roughly US$4–5 per unit at the prices observed during planning.
- Final assembly gains one coax connection and antenna adhesive operation.
- RF layout, antenna sourcing, placement, and boost-converter noise become explicit validation risks.
- Cost must still be verified from a complete five-unit landed quote before ordering.

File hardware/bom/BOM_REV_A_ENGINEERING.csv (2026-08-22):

Designator | Qty | Value / function | Manufacturer | Manufacturer part number | Package / footprint | Population | Initial electrical selection | Status / verification required
U1 | 1 | RP2040 microcontroller | Raspberry Pi | RP2040 | QFN-56 7 x 7 mm | Fit | 3.3 V; native USB; local 1V1 DVDD bypass | Verify exposed pad, supply pins and decoupling placement
U2 | 1 | 2 MB QSPI boot flash | Winbond | W25Q16JVUXIQ | USON-8 2 x 3 mm | Fit | 2.7–3.6 V | Verify package pinout and RP2040 ROM compatibility
X1 | 1 | 12 MHz crystal | Abracon | ABM8-272-T3 | 3.2 x 2.5 mm | Fit | CL 10 pF; 50 ohm max ESR; 200 uW max drive | Raspberry Pi reference part; verify startup and temperature margin
U3 | 1 | 1-cell Li-Ion power-path charger | Texas Instruments | BQ24074RGTR | RGT0016C VQFN-16 3 x 3 mm | Fit | USB500; 404 mA nominal charge; custom TI land/stencil without via-in-pad | Verify TS, timers, input limit, exposed pad and thermal test
U4 | 1 | 3.3 V buck-boost system regulator | Texas Instruments | TPS63802DLAR | VSON-HR-10 3 x 2 mm | Fit | 3.3 V; 0.47 uH; 511k/91k | Verify HotRod land pattern and switching layout against TI drawing
LBB1 | 1 | Buck-boost inductor | Coilcraft | XFL4020-471MEC | 4 x 4 mm | Fit | 0.47 uH, saturation margin TBD | Validate current/thermal margin
U5 | 1 | 5 V LCD boost | Texas Instruments | TPS61023DRLR | SOT-563-6 | Fit | 5.045 V nominal; 909k/100k feedback; GPIO5 enable | Validate 1 uH and output with measured LCD load
LLCD1 | 1 | LCD boost inductor | Murata | LQH2MCN1R0M02L | 2016 metric | Fit | 1.0 uH | Verify saturation and EMI
U6 | 1 | Dual-rail LCD level translator | Texas Instruments | SN74LVC8T245PWR | TSSOP-24 | Fit | VCCA 3.3 V; VCCB 5 V; A-to-B | Verify partial-power-down behavior and OE/DIR straps
U7 | 1 | GNSS receiver | Ai-Thinker | GP-02 | SMD-18 9.9 x 10.3 mm, 1.12 mm pitch | Fit | 3.3 V switched UART NMEA | Land and pin numbers follow manufacturer drawing; verify ordered module lot and RF topology
U8 | 1 | GNSS load switch | Texas Instruments | TPS22916BYFPR | YFP DSBGA-4, 0.78 x 0.78 mm, 0.4 mm pitch | Fit | GPIO18 active high | Land follows TI YFP0004 drawing; verify assembly capability and ordered suffix
J4 | 1 | GNSS RF connector | Hirose | 20449-001E | u.FL surface mount | Fit | 50-ohm coax launch | Verify exact land and CPWG from ordered stack-up
ANT1 | 1 | Internal passive L1 patch + coax | Taoglas | CGGBP.25.4.A.02 | 25 x 25 mm / 100 mm u.FL | External | 1575.42 MHz passive patch | Provisional; verify ground plane, loss, fit and availability
J1 | 1 | USB-C USB2 receptacle | GCT | USB4105-GF-A | top-mount horizontal | Fit | USB 2.0 sink; fused VBUS | Project land shortens four end GND pads to 1.0 mm for NPTH clearance; verify against fab capability and enclosure
D1 | 1 | Rail-less USB D+/D- ESD suppressor | Texas Instruments | TPD2EUSB30DRTR | DRT0003A SOT-9X3 1 x 1 mm | Fit | 0.7 pF typical; passive ground-only TVS | Exact TI pin order D+=1, D-=2, GND=3; no VBUS steering/backfeed path
RCC1,RCC2 | 2 | USB-C Rd | Yageo | RC0402FR-075K1L | 0402 | Fit | 5.1 kΩ 1% | Independent CC resistors
F1 | 1 | USB input PTC | Bourns | MF-MSMF050-2 | 1812 | Fit | 0.50 A hold | Validate drop and trip margin with system plus charging load
J2 | 1 | Battery connector | JST | B3B-PH-K-S(LF)(SN) | THT vertical | Fit | BAT+, NTC, GND | Verify cell harness polarity and keyed mating part
BAT1 | 1 | Protected 1S LiPo nominal 1000 mAh | EEMB | LP603450-PCM-3W | pouch / JST-PH 3-wire | External | 3.7 V nominal | Provisional: PCM IQ, NTC, dimensions and transport documents required
TH1 | 1 | Cell NTC fallback | Murata | NCP18XH103F03RB | 0603 | DNP with pack NTC | 10 kΩ B=3380–3435 K | Bond to pouch and validate BQ24074 thresholds
Q1,Q4 | 2 | P-channel signal/sense switches | Diodes Incorporated | DMP3098L-7 | SOT-23 | Fit | Q1 only drives EN; Q4 isolates BAT ADC | Verify pinout and off leakage
Q2,Q3,Q5 | 3 | N-channel latch/backlight/sense MOSFET | Diodes Incorporated | DMN2050L-7 | SOT-23 | Fit | logic-level gate | Verify pinout, leakage and Q3 LED current
SW1,SW2 | 2 | Side LOCATE/OFF tactile | E-Switch | TL1014BF160QG | right-angle SMD with bosses | Fit | 160 gf | Land and actuator datum follow manufacturer drawing; sealing remains enclosure-level
SW3,SW4 | 2 | Internal BOOTSEL/RUN tactile | Panasonic | EVQ-P7A01P | EVQP7A SMD | Fit | service access | Verify BOOTSEL QSPI isolation and access
J3 | 1 | 16-pin LCD header | Wurth Elektronik | 61301611121 | 1x16 2.54 mm THT | Fit | 5 V write-only 4-bit bus | Verify LCD pin-1 and physical stacking
LCD1 | 1 | Blue 16x2 LCD | Winstar | WH1602B-YYK-CTK | 80 x 36 mm | External | 5 V HD44780-compatible | Representative; freeze sample and measure BL current/contrast
LED1 | 1 | Charge indicator red LED | Kingbright | KP-2012EC | 0805 | Fit | 3V3 through RCHG1/LED to CHG_N | Confirm light-pipe brightness and status current
R/C network | 1 set | Reference passives | Yageo / Murata | See PASSIVES_REV_A_ENGINEERING.csv | 0402/0603 | Fit | Values in connected source | Review every value against final vendor circuits

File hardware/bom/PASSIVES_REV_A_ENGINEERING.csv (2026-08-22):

Designator | Value | Suggested MPN | Purpose | Review status
C1-C9,CDV1,CDV2,CFLASH1,CULS1,CULD1,CRESET1,CBATADC1,CGNSS1 | 100 nF X7R | Murata GRM155R71C104KA88D | RP2040 3V3/1V1 and peripheral decoupling; ADC/GNSS bypass | CDV1/CDV2 are local to DVDD pins 23/50; CBATADC1 firmware settle time required
CVREG1,CADC1 | 1 uF X7R | Murata GRM155R60J105KE19D | RP2040 VREG/ADC supply | Follow RP2040 hardware guide
CX1,CX2 | 15 pF C0G | Murata GRM1555C1H150JA01D | 12 MHz crystal load | Raspberry Pi ABM8-272-T3 reference network; verify startup and stray capacitance
CIN1 | 1 uF X7R | Murata GRM155R61A105KE15D | BQ24074 input | Verify effective bias capacitance
CBAT1,COUT1 | 4.7 uF X7R | Murata GRM188R61A475KE15D | BQ24074 BAT/OUT | Verify reference circuit and load transient
CBBIN1,CBBOUT1 | 10 uF / 22 uF X7R | Murata GRM21BR61A106KE19L / GRM21BR60J226ME39L | TPS63802 input/output | Meet effective-capacitance minimum under bias
CLCDIN1,CLCDO1,CLCDO2 | 10 uF / 10 uF / 10 uF X7R | Murata GRM21BR61A106KE19L | TPS61023 input/output | Keep switching loop compact
CGIN1,CGOUT1 | 1 uF / 4.7 uF X7R | Murata GRM155R60J105KE19D / GRM188R61A475KE15D | GNSS load switch | Verify GP-02 transient
RUSB1,RUSB2 | 27 ohm 1% | Yageo RC0402FR-0727RL | RP2040 USB required series resistors | Place at MCU and route differential pair
RBOOT1 | 1 kΩ 1% | Yageo RC0402FR-071KL | QSPI CSn to BOOTSEL switch isolation | RP2040 reference-design recovery path
RXTAL1 | 1 kΩ 1% | Yageo RC0402FR-071KL | RP2040 XOUT crystal drive limiting | Raspberry Pi 3.3 V reference recommendation
RISET1 | 2.20 kΩ 1% | Yageo RC0402FR-072K2L | BQ24074 ~404 mA fast-charge set | Must not exceed frozen cell rating
RILIM1 | 2.00 kΩ 1% | Yageo RC0402FR-072KL | BQ24074 programmable limit fallback | USB500 selected by EN pins; verify state
RITERM1 | 3.30 kΩ 1% | Yageo RC0402FR-073K3L | BQ24074 termination | Verify against frozen cell/RISET1
RTMR1 | 48.7 kΩ 1% | Yageo RC0402FR-0748K7L | BQ24074 safety timer | Verify desired precharge/fast-charge timeout
RBB1,RBB2 | 511 kΩ / 91 kΩ 1% | Yageo RC0402FR-07511KL / RC0402FR-0791KL | TPS63802 3.3 V feedback | TI 3.3 V typical circuit values
RLCD1,RLCD2 | 909 kΩ / 100 kΩ 1% | Yageo RC0402FR-07909KL / RC0402FR-07100KL | TPS61023 5.045 V nominal at 0.5 V VREF | Verify tolerance and output under load
REN1 | 1 MΩ | Yageo RC0402FR-071ML | Enable off-state bias | Include tolerance and contamination in leakage test
RBATG1 | 100 kΩ | Yageo RC0402FR-07100KL | Battery-sense P-channel gate off bias | Limits Q5 leakage-induced gate error; verify shutdown drain
RSTART1 | 100 kΩ | Yageo RC0402FR-07100KL | Q1 gate-source off bias | Bounds diode/Q2 leakage-induced VGS; verify press current and hot leakage
RBAT1,RBAT2 | 100 kΩ / 100 kΩ 1% | Yageo RC0402FR-07100KL | Switched 2:1 battery divider | Calibrate with ADC settle capacitor
RVB1,RVB2 | 82 kΩ / 100 kΩ 1% | Yageo RC0402FR-0782KL / RC0402FR-07100KL | VBUS-present divider; 2.75 V at 5.0 V | Verify 5.5 V maximum remains below GPIO rail and no backfeed
RVO1,RVO2 | 4.7 kΩ / 560 Ω | Yageo RC0402FR-074K7L / RC0402FR-07560RL | Fixed LCD contrast start point | Adjust after exact LCD sample
RBL1 | 68 Ω 0603 | Yageo RC0603FR-0768RL | Safe-start external backlight limit | Change only after module resistor/current measurement
RCHG1 | 1 kΩ | Yageo RC0402FR-071KL | 3V3-fed charge-status LED current limit | Indicator branch is not the logic pull-up
RCHGPU1 | 100 kΩ | Yageo RC0402FR-07100KL | Explicit CHG_N logic pull-up to 3V3 | Keeps GPIO deterministic if LED is absent or open
CGNSS2,CGNSS3 | 820 pF / 10 uF | Murata GRM1555C1H821JA01D / GRM21BR61A106KE19L | GP-02 local reference bypass | Place immediately at module VCC/GND pins
RGNSSTX1,RGNSSRX1 | 33 ohm 1% | Yageo RC0402FR-0733RL | GP-02 UART source damping | Place adjacent to module UART pads
RLOC1,ROFF1,RRESET1,RGNSSEN1,RLCDEN1,RHOLD1,RSENSEEN1 | 100 kΩ | Yageo RC0402FR-07100KL | Deterministic reset/off pulls | RHOLD1 and RSENSEEN1 force off during reset/unpowered states
D2,D4 | BAT54-series Schottky | Nexperia BAT54H | VBUS and start-enable diode OR | Verify polarity and leakage over temperature
D3,D5 | Low-leak silicon signal diode | Diodes Incorporated 1N4148WS-7-F | LOCATE_RAW gate/report isolation | Low reverse leakage protects off-state margin; verify worst case across temperature

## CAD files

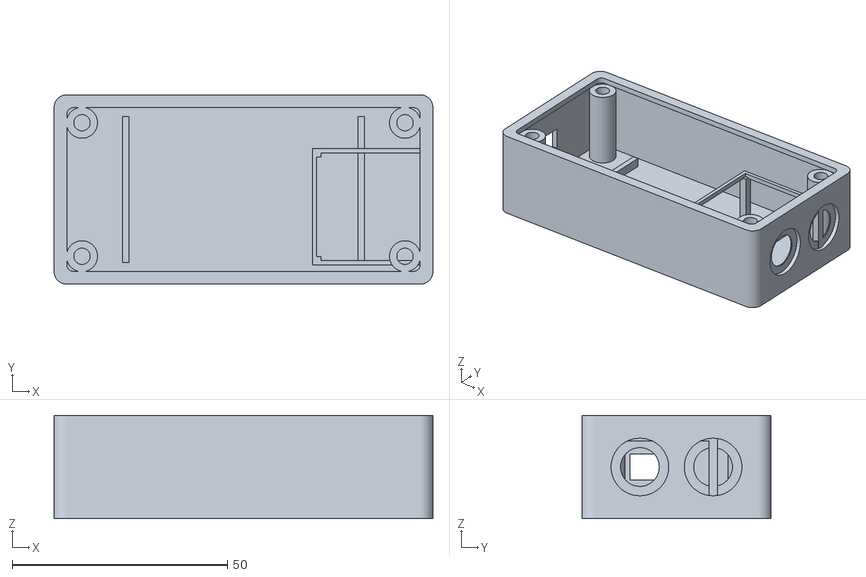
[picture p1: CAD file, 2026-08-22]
enclosure/exports/base.stl
88.0 x 44.0 x 24.0

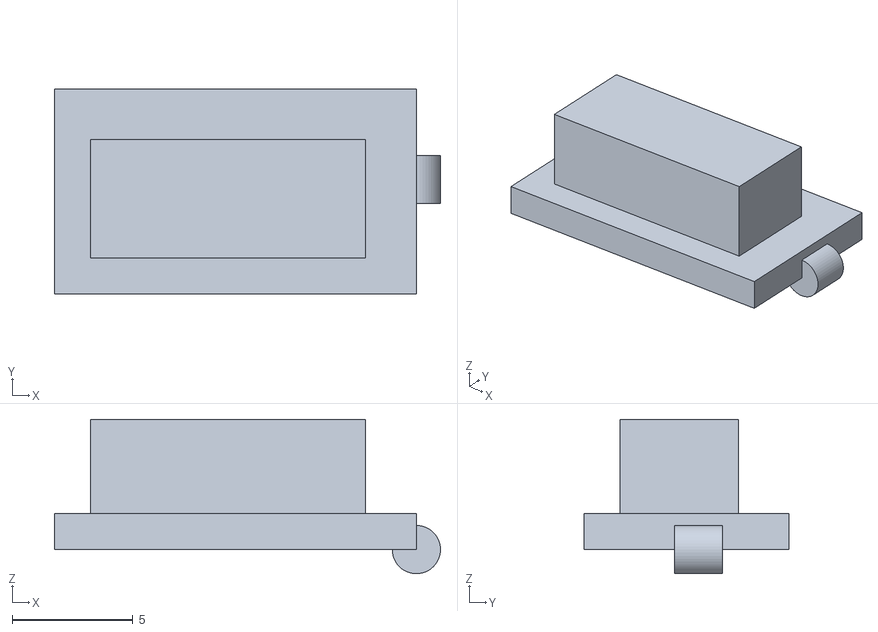
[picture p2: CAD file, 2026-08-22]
enclosure/exports/usb-plug.stl
16.0 x 8.50 x 6.40

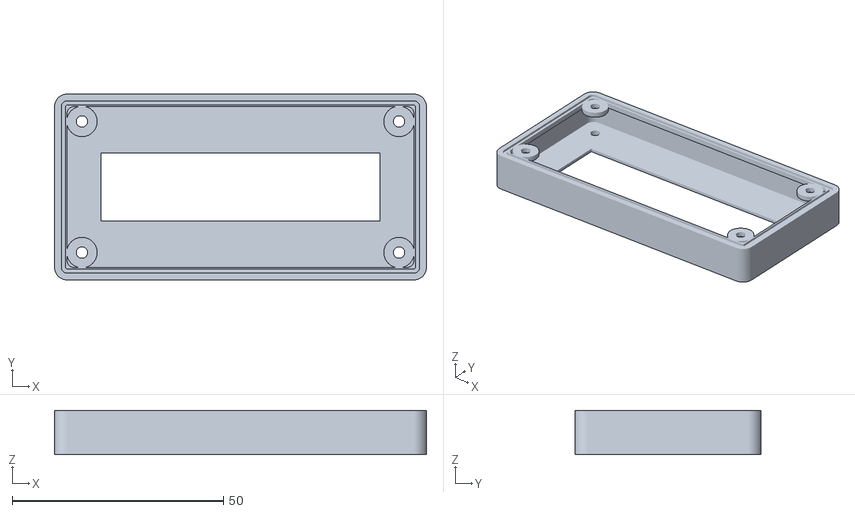
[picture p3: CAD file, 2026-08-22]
enclosure/exports/lid.stl
88.0 x 44.0 x 10.5

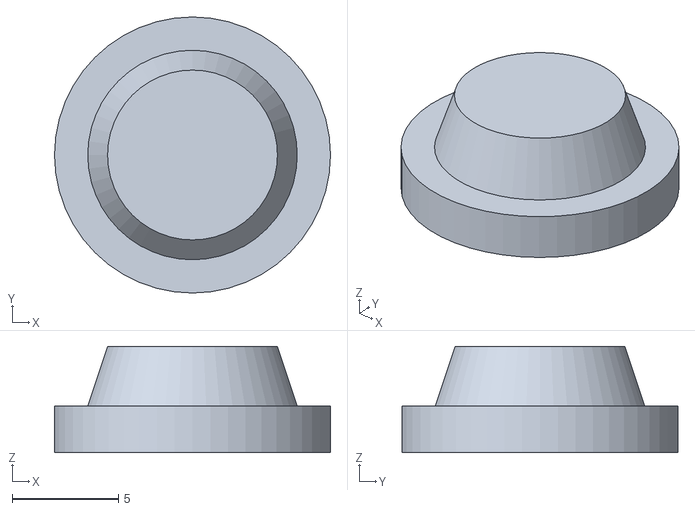
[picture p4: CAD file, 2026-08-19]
enclosure/exports/button-boot.stl
13.0 x 13.0 x 5.00

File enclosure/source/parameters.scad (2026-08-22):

// SPDX-License-Identifier: CERN-OHL-S-2.0

outer_width = 88;
outer_height = 44;
assembled_depth = 34.5;
corner_radius = 3;
// A 1.5 mm shell leaves 2 mm internal clearance on every side of the centered
// 81 x 37 mm engineering PCB. The local mating flange leaves 0.5 mm per side.
wall = 1.5;
floor_thickness = 2.0;
lid_thickness = 2.0;
base_depth = 24.0;
lid_depth = assembled_depth - base_depth;

lcd_visible_width = 66.0;
lcd_visible_height = 16.0;
lcd_window_width = 71.0;
lcd_window_height = 25.0;
lcd_window_thickness = 1.0;
lcd_window_recess_depth = 1.1;
lcd_window_corner_radius = 1.5;
lcd_board_width = 80.0;
lcd_board_height = 36.0;
lcd_total_depth = 13.5;
lcd_mount_pitch_x = 75.0;
lcd_mount_pitch_y = 31.0;

pcb_width = 81.0;
pcb_height = 37.0;
pcb_thickness = 1.6;
pcb_edge_clearance = 0.5;

gasket_width = 1.0;
gasket_depth = 0.7;
gasket_diameter = 1.0;
gasket_inset = 1.6;
mating_flange_inset = 3.0;
mating_flange_thickness = 1.5;
screw_inset = 6.5;
screw_clearance = 2.7;
insert_diameter = 3.8;

button_diameter = 9.0;
button_spacing = 17.0;
button_1_center = 13.5;
button_2_center = 30.5;
button_recess = 1.2;
usb_width = 12.0;
usb_height = 5.5;
usb_clearance = 0.3;
usb_center = 17.5;
interface_center_z = base_depth / 2;

battery_width = 52.0;
battery_height = 34.0;
battery_depth = 7.0;
battery_clearance = 0.6;
antenna_width = 25.0;
antenna_height = 25.0;
antenna_depth = 4.0;

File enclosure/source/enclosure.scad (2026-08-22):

// SPDX-License-Identifier: CERN-OHL-S-2.0
// Render `part` as "base", "lid", "button", "usb_plug", or "assembly".

include <parameters.scad>

part = "assembly";
$fn = 48;

module rounded_box(size, radius) {
    hull() {
        for (x = [radius, size[0] - radius])
            for (y = [radius, size[1] - radius])
                translate([x, y, 0]) cylinder(h = size[2], r = radius);
    }
}

module rounded_prism_2d(size, height, radius) {
    linear_extrude(height = height)
        offset(r = radius)
            square([size[0] - 2 * radius, size[1] - 2 * radius], center = true);
}

module gasket_groove(z) {
    difference() {
        translate([gasket_inset, gasket_inset, z])
            rounded_box([outer_width - 2 * gasket_inset,
                         outer_height - 2 * gasket_inset,
                         gasket_depth + 0.2], corner_radius - gasket_inset);
        translate([gasket_inset + gasket_width, gasket_inset + gasket_width, z - 0.1])
            rounded_box([outer_width - 2 * (gasket_inset + gasket_width),
                         outer_height - 2 * (gasket_inset + gasket_width),
                         gasket_depth + 0.4],
                        corner_radius - gasket_inset - gasket_width);
    }
}

module mating_flange(z) {
    difference() {
        translate([0, 0, z])
            rounded_box([outer_width, outer_height, mating_flange_thickness], corner_radius);
        translate([mating_flange_inset, mating_flange_inset, z - 0.1])
            rounded_box([outer_width - 2 * mating_flange_inset,
                         outer_height - 2 * mating_flange_inset,
                         mating_flange_thickness + 0.2],
                        corner_radius - mating_flange_inset / 2);
    }
}

module screw_bosses(z, height, bore) {
    for (x = [screw_inset, outer_width - screw_inset])
        for (y = [screw_inset, outer_height - screw_inset])
            translate([x, y, z - 0.2]) difference() {
                cylinder(h = height + 0.2, d = 7.2);
                translate([0, 0, -0.1]) cylinder(h = height + 0.4, d = bore);
            }
}

module base() {
    difference() {
        rounded_box([outer_width, outer_height, base_depth], corner_radius);
        translate([wall, wall, floor_thickness])
            rounded_box([outer_width - 2 * wall, outer_height - 2 * wall,
                         base_depth], corner_radius - wall / 2);
        // Side-button apertures aligned to PCB actuator-tip Y coordinates +3.5 mm.
        for (y = [button_1_center, button_2_center])
            translate([outer_width - wall - 0.2, y, interface_center_z])
                rotate([0, 90, 0]) cylinder(h = wall + 0.5, d = button_diameter);
        // Outside counterbores protect and locate the bonded boot flanges.
        for (y = [button_1_center, button_2_center])
            translate([outer_width - button_recess, y, interface_center_z])
                rotate([0, 90, 0])
                    cylinder(h = button_recess + 0.2, d = button_diameter + 4.4);
        // USB-C opening aligned to the PCB connector mating face at x=0, y=14.
        translate([-0.2, usb_center - usb_width / 2 - usb_clearance,
                   interface_center_z - usb_height / 2 - usb_clearance])
            cube([wall + 0.5, usb_width + 2 * usb_clearance,
                  usb_height + 2 * usb_clearance]);
    }
    mating_flange(base_depth - mating_flange_thickness);
    screw_bosses(floor_thickness, base_depth - floor_thickness - 1.5, insert_diameter);
    // Battery rails; no compression against the pouch.
    battery_x = (outer_width - battery_width) / 2;
    battery_y = (outer_height - battery_height) / 2;
    for (x = [battery_x - battery_clearance - 1.5,
              battery_x + battery_width + battery_clearance])
        translate([x, battery_y, floor_thickness]) cube([1.5, battery_height, 2.5]);
    // Antenna shelf beneath the top wall, clear of battery and PCB copper.
    // Overlap the frame into the right wall so it is printable, not a floating body.
    antenna_x = outer_width - antenna_width - wall - 1.5;
    antenna_y = wall + 3;
    antenna_z = base_depth - antenna_depth - 2;
    translate([antenna_x, antenna_y,
               base_depth - antenna_depth - 2])
        difference() {
            cube([antenna_width + 2, antenna_height + 2, 1.2]);
            translate([1, 1, -0.1]) cube([antenna_width, antenna_height, 1.4]);
        }
    // Four integrated posts make the antenna frame a printable, retained body.
    for (x = [antenna_x, antenna_x + antenna_width])
        for (y = [antenna_y, antenna_y + antenna_height])
            translate([x, y, floor_thickness - 0.2])
                cube([2, 2, antenna_z - floor_thickness + 0.4]);
}

module lid() {
    difference() {
        union() {
            difference() {
                rounded_box([outer_width, outer_height, lid_depth], corner_radius);
                translate([wall, wall, lid_thickness])
                    rounded_box([outer_width - 2 * wall, outer_height - 2 * wall,
                                 lid_depth], corner_radius - wall / 2);
                // Flush exterior pocket for the 1 mm polycarbonate window.
                translate([outer_width / 2, outer_height / 2, -0.1])
                    rounded_prism_2d([lcd_window_width, lcd_window_height],
                                     lcd_window_recess_depth + 0.1,
                                     lcd_window_corner_radius);
                // Smaller through-aperture leaves the continuous window seal land.
                translate([(outer_width - lcd_visible_width) / 2,
                           (outer_height - lcd_visible_height) / 2,
                           lcd_window_recess_depth - 0.05])
                    cube([lcd_visible_width, lcd_visible_height,
                          lid_thickness - lcd_window_recess_depth + 0.3]);
            }
            mating_flange(lid_depth - mating_flange_thickness);
            // Reinforced hard-stop lands around the four through screws.
            for (x = [screw_inset, outer_width - screw_inset])
                for (y = [screw_inset, outer_height - screw_inset])
                    translate([x, y, lid_depth - 1.4])
                        cylinder(h = 1.4, d = 7.2);
        }
        gasket_groove(lid_depth - gasket_depth);
        for (x = [screw_inset, outer_width - screw_inset])
            for (y = [screw_inset, outer_height - screw_inset])
                translate([x, y, -0.1]) cylinder(h = lid_depth + 0.2, d = screw_clearance);
    }
}

module button_boot() {
    difference() {
        union() {
            cylinder(h = 2.2, d = button_diameter + 4);
            translate([0, 0, 2.0]) cylinder(h = 3.0, d1 = button_diameter + 1, d2 = button_diameter - 1);
        }
        translate([0, 0, -0.1]) cylinder(h = 1.4, d = button_diameter - 2);
    }
}

module usb_plug() {
    union() {
        translate([-1.5, -1.5, 0]) cube([usb_width + 3, usb_height + 3, 1.5]);
        translate([0, 0, 1.4])
            cube([usb_width - 2 * usb_clearance,
                  usb_height - 2 * usb_clearance, 4.0]);
        translate([usb_width + 1.5, usb_height / 2 + 1.5, 0])
            rotate([90, 0, 0]) cylinder(h = 2.0, d = 2.0);
    }
}

if (part == "base") base();
else if (part == "lid") lid();
else if (part == "button") button_boot();
else if (part == "usb_plug") usb_plug();
else {
    color("DarkSlateGray") base();
    // Exploded view: flip the lid so its open mating face points toward the base.
    translate([0, outer_height, base_depth + lid_depth + 2])
        rotate([180, 0, 0]) color("SteelBlue", 0.7) lid();
}

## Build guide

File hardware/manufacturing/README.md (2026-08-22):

# Manufacturing artifact workflow

SPDX-License-Identifier: CC-BY-SA-4.0

The KiCad source is the controlled artifact. Generated files in
`review-output/` are deliberately ignored because they must be regenerated
from the reviewed commit and the selected fabricator settings.

```sh
python3 hardware/manufacturing/preflight.py --source-only
python3 hardware/manufacturing/preflight.py
hardware/manufacturing/export.sh
```

`--source-only` is a diagnostic check: it validates source, critical nets, BOM
and outline while reporting any DRC/unconnected work as pending. It is not
permission to order. CI and `export.sh` use the default manufacturing gate,
which fails until KiCad DRC, routing, and plane-fill checks pass. Exact ordered-part
drawings, physical overlays, and the three provisional external selections remain
explicit manual checklist gates.

`export.sh` runs the default manufacturing gate, archives its complete DRC,
then atomically replaces the review directory with SVG, top assembly PDF, Gerbers,
drill, IPC-D-356, a millimetre/SMD-only placement file, schematic PDF/netlist,
searchable HTML BOM and BOM CSVs. The BOM status column remains authoritative for
assembly-provider, hand-install, provisional, and do-not-fit decisions; the placement
file alone is not an assembly instruction. `assembly-bom.csv` and `placement.csv`
have matched one-reference-per-row contents; the CPL uses JLC's standard Designator,
Mid X, Mid Y, Layer, and Rotation headers. Supplier/LCSC part selections remain a
manual release gate until the exact quote is frozen.
KiCad 7.0's CLI does not expose schematic ERC, so archive the signed-off GUI ERC
report with release evidence. A clean export alone is not a fabrication approval.

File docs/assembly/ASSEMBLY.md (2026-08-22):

# Assembly guide

**Engineering draft — do not use for a production build until every item in the
[manufacturing release checklist](../manufacturing/RELEASE_CHECKLIST.md) is signed.**
The sequence below does not establish that the current PCB and enclosure fit.

## Safety

Use only the protected, keyed 1-cell LiPo listed in the released BOM. Never bend,
puncture, clamp, solder directly to, or reverse-connect a pouch cell. Stop if the
cell is swollen, damaged, hot, or below its supplier's safe voltage. This device
is not an emergency locator, navigation instrument, or immersion-rated product.

## Preparation

1. Complete the first-board electrical procedure in [BRINGUP.md](BRINGUP.md).
2. Confirm the PCB revision, firmware revision, enclosure revision, and BOM match.
3. Dry-fit the LCD, PCBA, cell dummy, patch antenna, coax, window, gasket, buttons,
   USB plug, and fasteners without the live cell.
4. Clean the window land and polycarbonate with materials compatible with both.

## Mechanical assembly

1. Install heat-set inserts using a temperature-controlled tool and a depth stop.
   Let the parts cool before checking screw alignment.
2. Bond the 71 × 25 × 1 mm polycarbonate window into the 1.1 mm lid recess with a
   continuous closed-cell adhesive seal. Leave no seam at the corners.
3. Fit the LCD behind the window without loading the display glass. Secure its PCB
   only with the released supports/fasteners and connect the keyed header.
4. Fit the two elastomer button boots. Verify their outer flanges remain flat and
   each tactile switch returns freely before installing electronics.
5. Mount the passive patch ceramic face toward the top wall. Keep the specified
   copper/metal/battery exclusion volume and avoid a sharp bend at either coax end.
6. Install the PCBA and route the coax away from the 5 V inductor, USB pair, LCD
   edge, and screw bosses. Seat the u.FL plug vertically with a plastic tool.
7. Place the protected cell between the retention rails with no foam pressure on
   the pouch. Route its lead without pinch points and connect the keyed plug last.
8. Fit the released nominal 1 mm silicone cord dry and continuous in its 0.7 mm
   groove. Do not stretch it; place the bonded splice only as the seal procedure specifies.
9. Close the lid and tighten screws in a diagonal sequence until the hard stops
   meet. Do not use screw torque to crush the gasket further.
10. Fit and tether the USB-C plug, then confirm the charging light pipe is visible.

Reject the assembly if any part requires force, bends the PCB/LCD, presses the
cell, violates the coax bend radius, prevents a seal from lying flat, or changes
button return. Do not “make it fit” by thinning a safety wall or omitting a gasket.

## Final functional check

- Confirm USB data, charging, configuration read-back, and BOOTSEL recovery.
- Confirm short button taps do not latch power and both one-second holds work.
- Acquire a current outdoor fix and compare the locator with an independent tool.
- Confirm the backlight dims and the unit shuts down at configured deadlines.
- Record unit serial, firmware, profile CRC, battery lot, and test result without
  recording the operator's coordinates.

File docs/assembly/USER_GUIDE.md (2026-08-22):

# User guide

**Draft for the future validated V1 hardware.** Timing, charging, sealing, thermal
cutoff, and recovery statements below are required behavior, not measured claims
about the current engineering sources.

Hold **LOCATE** for one second. The screen shows `ACQUIRING GPS` until it receives
a current valid GNSS fix; it never substitutes a cached position. For best results,
hold the unit face-up outdoors with a clear view of the sky. The factory session
dims after 60 seconds and ends after 120 seconds from the first button-down edge.

Hold **OFF** for one second to end early. While USB is connected, OFF returns the
device to a dark configuration-ready state. Hold both buttons for five seconds and
follow the countdown to restore factory settings.

The locator is intended for desks, portable amateur-radio outings, and occupied
vehicles. It is not a navigation device, emergency beacon, tracking device, or
substitute for checking conditions around a vehicle. Do not leave or charge it in
a hot parked vehicle.

## Charging and USB

Use a standards-compliant 5 V USB source and a data-capable USB-C cable. The red
indicator is lit while charging. Charging is inhibited when the cell sensor is
outside its permitted temperature range. Unplug and inspect the device if it
becomes unusually hot, smells unusual, or the enclosure/cell changes shape.

The enclosure target is resistance to drizzle, dust, and incidental sand with its USB cap
installed. It has no certified IP rating. Do not immerse it or charge it while wet.

## Configuration and recovery

Install Python 3.11+, Tkinter, and the configurator as described in the
[configurator guide](../../configurator/README.md). Profiles contain display and behavior settings but never
location history. Custom RP2040 UF2 firmware is allowed; back up the current profile
before every update.

If application firmware will not start, remove the rear cover, hold the labelled
internal **BOOTSEL** switch, attach USB, and release the switch when `RPI-RP2`
appears. Keep the cell and metal tools away from exposed electronics.

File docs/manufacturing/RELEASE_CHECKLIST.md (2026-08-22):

# Manufacturing release checklist

## Source and electrical

- [ ] Exact BOM manufacturer part numbers and approved substitutes frozen
- [ ] Manufacturer reference circuits checked component by component
- [ ] LCD backlight current and resistor configuration verified on sample
- [ ] Cell capacity/current/temperature limits match charger programming
- [ ] Power-path, VBUS enable, hard latch, and reverse-polarity behavior reviewed
- [ ] GP-02 RF trace recomputed from the fabricator's ordered stack-up
- [ ] ERC and DRC clean with intentional exceptions documented
- [ ] All footprints checked against physical drawings and pin-1 orientation

## Mechanical

- [ ] PCB, LCD, window, buttons, USB, antenna, cell, gasket share one datum model
- [ ] Frozen XY coordinates in `enclosure/INTERFACES.md` match PCB and enclosure exports
- [ ] Z stack and tolerances are frozen from exact drawings and measured samples
- [ ] 88 × 44 × ≤35 mm engineering envelope confirmed from exported geometry
- [ ] Coax and battery leads meet bend/strain clearance without forced compression
- [ ] Unpopulated dimensional fit-check printed and measured
- [ ] One complete enclosure printed before committing the remaining four

## Manufacturing artifacts

- [ ] Schematic PDF, Gerbers, drill, IPC/netlist, BOM, and pick-and-place regenerated
- [ ] Gerbers inspected in an independent viewer
- [ ] Assembly drawing shows DNP, polarity, and hand-installed parts
- [ ] Test points and BOOTSEL/RUN recovery controls are labelled and accessible
- [ ] Five-unit carts include tax, shipping, setup, minimums, and consumables
- [ ] Cart destination, currency/FX, expiry, shipping method, and promotions recorded
- [ ] Complete five-unit landed total is ≤US$150 before ordering

## Release evidence

- [ ] First-board bring-up completed without unsafe rework
- [ ] Full acceptance procedure passed on the released revision
- [ ] Firmware/configurator releases are reproducible from the tagged commit
- [ ] LiPo, heat, water-resistance, and non-emergency warnings are prominent
- [ ] Released artifacts contain no coordinates, secrets, or private supplier data
- [ ] [Evidence index](../testing/TEST_EVIDENCE.md) contains raw measured results
- [ ] [Order package](ORDER_PACKAGE.md) is complete and signed off

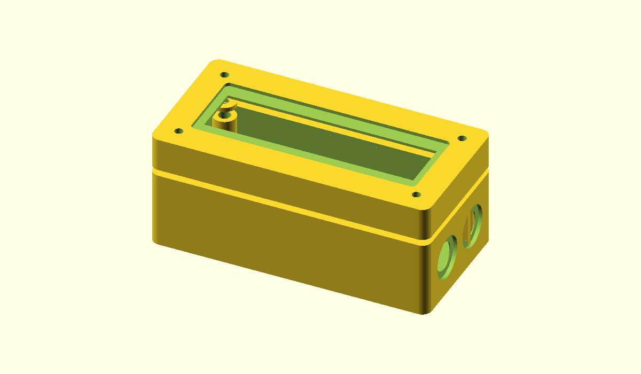
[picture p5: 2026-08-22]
enclosure/exports/assembly.png

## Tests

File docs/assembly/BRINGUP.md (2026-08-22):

# First-board bring-up

This procedure applies after the pre-order sections of the manufacturing release
checklist and the default manufacturing preflight pass. Its recorded result is an
input to the later release-evidence section; it is not a substitute for schematic
review or an electrical-safe work area.

1. Keep the battery disconnected. Inspect polarity, QFN alignment, connectors,
   antenna lead, and solder bridges.
2. With power absent, verify ground continuity and check each rail for shorts.
3. Apply a current-limited USB source and verify VBUS, charger output, and 3.3 V in
   that order. The 5 V LCD and GNSS rails must remain off in USB-idle mode.
4. Load minimal firmware incrementally: power hold, USB, buttons, switched 5 V LCD
   rail, ADC, then switched GNSS rail. Verify each disabled rail returns off.
5. Validate charger limits and NTC hot/cold inhibition before fitting the cell.
6. Prove internal BOOTSEL recovery before closing the gasketed enclosure.

Stop on unexpected current, heating, rail voltage, reversed polarity, or damaged
cell wiring. Record any rework before deciding whether the remaining boards are safe.

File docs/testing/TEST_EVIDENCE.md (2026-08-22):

# V1 test evidence index

This file is the release index for **measured** V1 evidence. It starts empty on
purpose: software checks and CAD exports are not evidence that a physical unit
passed the acceptance criteria. Add immutable raw files or dated records below,
then link them from the release tag.

| Gate | Required raw record | Release status |
|---|---|---|
| Software | CI run URL; native/unit test output; RP2040 build hash | Automated locally; immutable release record pending |
| Cold-start GNSS | Ten rows in `cold-start-record.csv`; at least 9 within timeout | Not measured |
| Eight-hour outing | 32 sessions plus reserve row in `outing-record.csv` | Not measured |
| Shutdown current | Three voltages and instrument burden in `power-record.csv` | Not measured |
| Charger / NTC / power path | Rows in `charging-record.csv` | Not measured |
| USB / update / BOOTSEL | Rows in `controls-recovery-record.csv` | Not measured |
| RF / orientation | Face-up, handheld, desk, vehicle, interference comparison | Not measured |
| Mechanical fit | Exact-stack rows in `mechanical-fit-record.csv` | Not measured |
| Environment | Drizzle, sand, drops, cycles, reseals, 40 °C in `environment-record.csv` | Not measured |
| Cost | Saved five-unit carts, shipping/tax/setup total ≤ US$150 | Not quoted |

Do not replace “Not measured” with an assertion. Record failed trials, rework,
and retests alongside passing evidence.

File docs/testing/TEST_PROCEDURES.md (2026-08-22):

# Acceptance test procedures

Every result must identify unit serial, PCB/enclosure/firmware revision, operator,
UTC date, equipment, ambient conditions, raw observations, and pass/fail outcome.
Failed units are not averaged away; record correction and a complete retest.
Use calibrated instruments within their current calibration interval. Attach raw
photos, logs, and instrument captures by content hash; do not put coordinates in
public artifacts.

## Dimensional fit and stack

Measure the PCB, LCD, window, cell dummy, antenna/coax, gasket, boots, connector,
and printed parts before applying power. Record worst-case clearances and compare
all connector/button/mount centers with `enclosure/INTERFACES.md`. Reject forced
compression, glass/PCB bending, cell pressure, pinched wires, coax below its stated
bend radius, blocked seals, or a total depth above 35 mm. Repeat after ten closures.

## Cold-start GNSS

Fully remove GNSS backup power for the receiver supplier's specified discharge
period. Place the assembled unit face-up at the same open-sky site for ten trials,
separated sufficiently to remain true cold starts. Start timing at initial LOCATE
button-down. Pass when at least 9 of 10 trials display a valid independently checked
grid within the configured 120-second timeout. Record satellites, fix quality, time,
orientation, and weather without retaining coordinates in released diagnostics.

## Shutdown current and one-year reserve

At 25 °C, insert a calibrated low-burden ammeter between cell and product. Measure
after hard shutdown at 4.2 V, nominal 3.7 V, and the released low-voltage threshold,
allowing transients to
settle. Pass only when every electronics measurement is at most 10 µA. Calculate
one-year remaining capacity from the worst measurement plus the selected cell
maker's self-discharge and aging limits; the conservative remainder must power one
measured full check session.

## Outing endurance

Use factory brightness and timers. Over eight hours, run four complete two-minute
checks per hour at evenly spaced intervals, 32 total. After the eighth hour, run one
additional complete reserve check. Record battery voltage/ADC before, periodically,
and after without recharging.

## Charging, NTC, and power path

With a protected fixture, verify input current limit, charge current, termination,
charge LED, operation while charging, and permitted absent-cell behavior. Simulate
the supplier-defined hot and cold NTC resistances without heating or freezing a
live pouch; charge current must stop. Repeat at 40 °C ambient and verify the actual
cell-adjacent sensor inhibits charging before the cell limit.

## RF interference and orientation

At one fixed site compare time-to-fix and signal diagnostics with LCD/boost off,
full brightness, dim brightness, USB active, and LCD updates. Repeat face-up,
handheld, desk-angle, and vehicle-dashboard orientations. A material degradation
triggers placement, grounding, switching-frequency, or filtering review before any
receiver substitution.

## Controls, recovery, and configuration

Exercise 100 ms and 500 ms taps, bounce, 1.00 s accepted holds within the documented
timing tolerance, stuck inputs, simultaneous
holds, and 1,000 mechanical cycles per button on a sacrificial enclosure. Interrupt
configuration writes at every two-slot phase and firmware updates before copy,
during copy, and before reconnect. Prove internal BOOTSEL recovery with application
flash invalid and no debugger.

## Environmental and mechanical

- Record print material, slicer/settings, gasket/adhesive lot, fastener torque or
  hard-stop confirmation, and pre-test mass. Inspect all internals and place dry
  absorbent indicator paper near every seam.
- With the USB plug fitted, spray drizzle from multiple directions for ten minutes.
  Dry the exterior before opening; pass only with no visible ingress.
- Expose seams/buttons/cap to dry beach-like sand, brush clean, actuate controls,
  then open and inspect for grains at electronics.
- Open/reseal the battery compartment ten times and repeat button/seal inspection.
- Drop from 1.0 m onto dry short grass over firm soil once on each broad face and
  once on each enclosure edge/corner selected in the test record; never onto people.
- Soak at 40 ±2 °C for two hours unpowered, then operate a complete check and charge
  test while monitoring the cell-adjacent sensor. Inspect enclosure shape, LCD, GNSS, cell temperature, and
  charger inhibition. Do not perform immersion testing or infer an IP rating.

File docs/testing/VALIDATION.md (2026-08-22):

# Validation evidence quick index

The canonical status and raw-file links belong in [TEST_EVIDENCE.md](TEST_EVIDENCE.md);
the procedures are in [TEST_PROCEDURES.md](TEST_PROCEDURES.md). Software CI is
necessary but does not satisfy the physical acceptance criteria.
Record revision, equipment, conditions, raw observations, failures, and retests.

- [ ] Ten discharged-backup open-sky cold starts; at least 9 fixes in timeout
- [ ] 32 two-minute sessions over eight hours, followed by one reserve check
- [ ] Shutdown current at full, half, and low cell voltage; maximum 10 uA at 25 C
- [ ] Charger current, termination, power path, absent-cell behavior, hot/cold NTC
- [ ] LCD/GNSS operation while charging and boost/LCD interference comparison
- [ ] Face-up, handheld, desk, and vehicle GNSS orientations
- [ ] 1,000 cycles per button and ten battery-compartment reseals
- [ ] Ten-minute multidirectional drizzle test with indicator paper
- [ ] Sand exposure, cleanup, actuation, and ingress inspection
- [ ] Soft-ground drops and 40 C operation/charge inhibition
- [ ] BOOTSEL recovery after interrupted/invalid application update
- [ ] Final dimensions and complete five-unit landed quote

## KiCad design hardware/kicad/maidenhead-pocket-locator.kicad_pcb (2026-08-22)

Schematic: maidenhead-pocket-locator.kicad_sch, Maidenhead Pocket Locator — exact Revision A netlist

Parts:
C1, C2, C3, C4, C5, C6, C7, C8, C9: 100nF; C_0402_1005Metric
CADC1: 1uF; C_0603_1608Metric
CBAT1: 4.7uF; C_0603_1608Metric
CBATADC1: 100nF; C_0402_1005Metric
CBBIN1: 10uF; C_0805_2012Metric
CBBOUT1: 22uF; C_0805_2012Metric
CDV1, CDV2: 100nF; C_0402_1005Metric
CFLASH1: 100nF; C_0402_1005Metric
CGIN1: 1uF; C_0402_1005Metric
CGNSS1: 100nF; C_0402_1005Metric
CGNSS2: 820pF; C_0402_1005Metric
CGNSS3: 10uF; C_0805_2012Metric
CGOUT1: 4.7uF; C_0603_1608Metric
CIN1: 1uF; C_0603_1608Metric
CLCDIN1: 10uF; C_0805_2012Metric
CLCDO1, CLCDO2: 10uF; C_0805_2012Metric
COUT1: 4.7uF; C_0603_1608Metric
CRESET1: 100nF; C_0402_1005Metric
CULD1: 100nF; C_0402_1005Metric
CULS1: 100nF; C_0402_1005Metric
CVREG1: 1uF; C_0603_1608Metric
CX1, CX2: 15pF; C_0402_1005Metric
D1: TPD2EUSB30DRTR; Texas_DRT0003A
D2, D4: BAT54H; D_SOD-323
D3, D5: 1N4148WS; D_SOD-323
F1: MF-MSMF050-2; Fuse_1812_4532Metric
J1: USB4105-GF-A
J2: B3B-PH-K-S(LF)(SN); JST_PH_B3B-PH-K_1x03_P2.00mm_Vertical
J3: 61301611121; PinHeader_1x16_P2.54mm_Vertical
J4: Hirose 20449-001E; U.FL_Hirose_U.FL-R-SMT-1_Vertical
LBB1: XFL4020-471MEC; L_Coilcraft_XxL4020
LED1: KP-2012EC; LED_0805_2012Metric
LLCD1: LQH2MCN1R0M02L; L_0805_2012Metric
Q1, Q4: DMP3098L-7; SOT-23
Q2, Q3, Q5: DMN2050L-7; SOT-23
RBAT1, RBAT2: 100k; R_0402_1005Metric
RBATG1: 100k; R_0402_1005Metric
RBB1: 511k; R_0402_1005Metric
RBB2: 91k; R_0402_1005Metric
RBL1: 68R; R_0603_1608Metric
RBOOT1: 1k; R_0402_1005Metric
RCC1, RCC2: 5.1k; R_0402_1005Metric
RCHG1: 1k; R_0402_1005Metric
RCHGPU1: 100k; R_0402_1005Metric
REN1: 1M; R_0402_1005Metric
RGNSSEN1: 100k; R_0402_1005Metric
RGNSSRX1: 33R; R_0402_1005Metric
RGNSSTX1: 33R; R_0402_1005Metric
RHOLD1: 100k; R_0402_1005Metric
RILIM1: 2.00k; R_0402_1005Metric
RISET1: 2.20k; R_0402_1005Metric
RITERM1: 3.30k; R_0402_1005Metric
RLCD1: 909k; R_0402_1005Metric
RLCD2: 100k; R_0402_1005Metric
RLCDEN1: 100k; R_0402_1005Metric
RLOC1: 100k; R_0402_1005Metric
ROFF1: 100k; R_0402_1005Metric
RRESET1: 100k; R_0402_1005Metric
RSENSEEN1: 100k; R_0402_1005Metric
RSTART1: 100k; R_0402_1005Metric
RTMR1: 48.7k; R_0402_1005Metric
RUSB1, RUSB2: 27R; R_0402_1005Metric
RVB1: 82k; R_0402_1005Metric
RVB2: 100k; R_0402_1005Metric
RVO1: 4.7k; R_0402_1005Metric
RVO2: 560R; R_0402_1005Metric
RXTAL1: 1k; R_0402_1005Metric
SW1, SW2: TL1014BF160QG; SW_TL1014B
SW3, SW4: EVQ-P7A01P; SW_SPST_EVQP7A
TH1: 10k NTC DNP; R_0603_1608Metric
TP1: VBUS; TestPoint_Pad_D1.5mm
TP2: BAT; TestPoint_Pad_D1.5mm
TP3: SYS_RAW; TestPoint_Pad_D1.5mm
TP4: 3V3; TestPoint_Pad_D1.5mm
TP5: 5V_LCD; TestPoint_Pad_D1.5mm
TP6: GND; TestPoint_Pad_D1.5mm
TP7: POWER_HOLD; TestPoint_Pad_D1.5mm
TP8: GNSS_TX; TestPoint_Pad_D1.5mm
TP9: GNSS_RX; TestPoint_Pad_D1.5mm
TP10: SWDIO; TestPoint_Pad_D1.5mm
TP11: SWCLK; TestPoint_Pad_D1.5mm
TP12: RUN_N; TestPoint_Pad_D1.5mm
TP13: BOOTSEL_N; TestPoint_Pad_D1.5mm
U1: RP2040; QFN-56-1EP_7x7mm_P0.4mm_EP3.2x3.2mm
U2: W25Q16JVUXIQ; Winbond_UX_8
U3: BQ24074RGTR; Texas_RGT0016C
U4: TPS63802DLAR; Texas_DLA0010A
U5: TPS61023DRLR; SOT-563
U6: SN74LVC8T245PWR; TSSOP-24_4.4x7.8mm_P0.65mm
U7: Ai-Thinker GP-02; GP-02
U8: TPS22916BYFPR; Texas_YFP0004
X1: ABM8-272-T3; Crystal_SMD_Abracon_ABM8G-4Pin_3.2x2.5mm

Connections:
1V1: CDV1.1 (1V1), CDV2.1 (1V1), CVREG1.1 (1V1), U1.23 (1V1), U1.45 (1V1), U1.50 (1V1)
3V3: C1.1 (3V3), C2.1 (3V3), C3.1 (3V3), C4.1 (3V3), C5.1 (3V3), C6.1 (3V3), C7.1 (3V3), C8.1 (3V3), C9.1 (3V3), CADC1.1 (3V3), CBBOUT1.1 (3V3), CFLASH1.1 (3V3), CGIN1.1 (3V3), CULS1.1 (3V3), RBB1.1 (3V3), RCHG1.1 (3V3), RCHGPU1.1 (3V3), RLOC1.1 (3V3), ROFF1.1 (3V3), RRESET1.1 (3V3), TP4.1, U1.1 (3V3), U1.10 (3V3), U1.22 (3V3), U1.33 (3V3), U1.42 (3V3), U1.43 (3V3), U1.44 (3V3), U1.48 (3V3), U1.49 (3V3), U2.8 (3V3), U4.6 (3V3), U6.1 (3V3), U6.2 (3V3), U8.A2 (3V3)
3V3_GNSS: CGNSS1.1 (3V3_GNSS), CGNSS2.1 (3V3_GNSS), CGNSS3.1 (3V3_GNSS), CGOUT1.1 (3V3_GNSS), U7.8 (3V3_GNSS), U8.A1 (3V3_GNSS)
5V_LCD: CLCDO1.1 (5V_LCD), CLCDO2.1 (5V_LCD), CULD1.1 (5V_LCD), J3.2 (5V_LCD), RBL1.1 (5V_LCD), RLCD1.1 (5V_LCD), RVO1.1 (5V_LCD), TP5.1, U5.6 (5V_LCD), U6.23 (5V_LCD), U6.24 (5V_LCD)
BAT: CBAT1.1 (BAT), J2.1 (BAT), Q4.2 (BAT), RBATG1.1 (BAT), TP2.1, U3.2 (BAT), U3.3 (BAT)
BAT_ADC: CBATADC1.1 (BAT_ADC), RBAT1.2 (BAT_ADC), RBAT2.1 (BAT_ADC), U1.38 (BAT_ADC)
BAT_SENSE_EN: Q5.1 (BAT_SENSE_EN), RSENSEEN1.1 (BAT_SENSE_EN), U1.32 (BAT_SENSE_EN)
BAT_SENSE_GATE: Q4.1 (BAT_SENSE_GATE), Q5.3 (BAT_SENSE_GATE), RBATG1.2 (BAT_SENSE_GATE)
BAT_SENSE_SW: Q4.3 (BAT_SENSE_SW), RBAT1.1 (BAT_SENSE_SW)
BB_FB: RBB1.2 (BB_FB), RBB2.1 (BB_FB), U4.4 (BB_FB)
BB_SW1: LBB1.1 (BB_SW1), U4.9 (BB_SW1)
BB_SW2: LBB1.2 (BB_SW2), U4.7 (BB_SW2)
BL_PWM: Q3.1 (BL_PWM), U1.15 (BL_PWM)
BOOTSEL_N: RBOOT1.2 (BOOTSEL_N), SW3.1 (BOOTSEL_N), TP13.1
CC1: J1.A5 (CC1), RCC1.1 (CC1)
CC2: J1.B5 (CC2), RCC2.1 (CC2)
CHG_ILIM: RILIM1.1 (CHG_ILIM), U3.12 (CHG_ILIM)
CHG_ISET: RISET1.1 (CHG_ISET), U3.16 (CHG_ISET)
CHG_ITERM: RITERM1.1 (CHG_ITERM), U3.15 (CHG_ITERM)
CHG_LED_A: LED1.2 (CHG_LED_A), RCHG1.2 (CHG_LED_A)
CHG_N: LED1.1 (CHG_N), RCHGPU1.2 (CHG_N), U1.31 (CHG_N), U3.9 (CHG_N)
CHG_TMR: RTMR1.1 (CHG_TMR), U3.14 (CHG_TMR)
CHG_TS: J2.2 (CHG_TS), TH1.1 (CHG_TS), U3.1 (CHG_TS)
GND: C1.2 (GND), C2.2 (GND), C3.2 (GND), C4.2 (GND), C5.2 (GND), C6.2 (GND), C7.2 (GND), C8.2 (GND), C9.2 (GND), CADC1.2 (GND), CBAT1.2 (GND), CBATADC1.2 (GND), CBBIN1.2 (GND), CBBOUT1.2 (GND), CDV1.2 (GND), CDV2.2 (GND), CFLASH1.2 (GND), CGIN1.2 (GND), CGNSS1.2 (GND), CGNSS2.2 (GND), CGNSS3.2 (GND), CGOUT1.2 (GND), CIN1.2 (GND), CLCDIN1.2 (GND), CLCDO1.2 (GND), CLCDO2.2 (GND), COUT1.2 (GND), CRESET1.2 (GND), CULD1.2 (GND), CULS1.2 (GND), CVREG1.2 (GND), CX1.2 (GND), CX2.2 (GND), D1.3 (GND), J1.A1 (GND), J1.A12 (GND), J1.B1 (GND), J1.B12 (GND), J1.S1 (GND), J2.3 (GND), J3.1 (GND), J3.5 (GND), J3.7 (GND), J3.8 (GND), J3.9 (GND), J3.10 (GND), J4.2 (GND), Q2.2 (GND), Q3.2 (GND), Q5.2 (GND), RBAT2.2 (GND), RBB2.2 (GND), RCC1.2 (GND), RCC2.2 (GND), REN1.2 (GND), RGNSSEN1.2 (GND), RHOLD1.2 (GND), RILIM1.2 (GND), RISET1.2 (GND), RITERM1.2 (GND), RLCD2.2 (GND), RLCDEN1.2 (GND), RSENSEEN1.2 (GND), RTMR1.2 (GND), RVB2.2 (GND), RVO2.2 (GND), SW1.2 (GND), SW1.4 (GND), SW2.2 (GND), SW2.4 (GND), SW3.2 (GND), SW4.2 (GND), TH1.2 (GND), TP6.1, U1.19 (GND), U1.57 (GND), U2.4 (GND), U3.4 (GND), U3.5 (GND), U3.8 (GND), U3.17 (GND), U4.2 (GND), U4.3 (GND), U4.8 (GND), U5.4 (GND), U6.9 (GND), U6.10 (GND), U6.11 (GND), U6.12 (GND), U6.13 (GND), U6.22 (GND), U7.1 (GND), U7.10 (GND), U7.12 (GND), U8.B1 (GND), X1.2 (GND), X1.4 (GND)
GNSS_EN: RGNSSEN1.1 (GNSS_EN), U1.29 (GNSS_EN), U8.B2 (GNSS_EN)
GNSS_PPS: U7.4 (GNSS_PPS)
GNSS_RF_50R: J4.1 (GNSS_RF_50R), U7.11 (GNSS_RF_50R)
GNSS_RX: RGNSSRX1.1 (GNSS_RX), TP9.1, U1.27 (GNSS_RX)
GNSS_RX_U7: RGNSSRX1.2 (GNSS_RX_U7), U7.3 (GNSS_RX_U7)
GNSS_TX: RGNSSTX1.2 (GNSS_TX), TP8.1, U1.28 (GNSS_TX)
GNSS_TX_U7: RGNSSTX1.1 (GNSS_TX_U7), U7.2 (GNSS_TX_U7)
LCD_BL_A: J3.15 (LCD_BL_A), RBL1.2 (LCD_BL_A)
LCD_BL_K: J3.16 (LCD_BL_K), Q3.3 (LCD_BL_K)
LCD_D4: J3.11 (LCD_D4), U6.19 (LCD_D4)
LCD_D4_3V3: U1.11 (LCD_D4_3V3), U6.5 (LCD_D4_3V3)
LCD_D5: J3.12 (LCD_D5), U6.18 (LCD_D5)
LCD_D5_3V3: U1.12 (LCD_D5_3V3), U6.6 (LCD_D5_3V3)
LCD_D6: J3.13 (LCD_D6), U6.17 (LCD_D6)
LCD_D6_3V3: U1.13 (LCD_D6_3V3), U6.7 (LCD_D6_3V3)
LCD_D7: J3.14 (LCD_D7), U6.16 (LCD_D7)
LCD_D7_3V3: U1.14 (LCD_D7_3V3), U6.8 (LCD_D7_3V3)
LCD_E: J3.6 (LCD_E), U6.20 (LCD_E)
LCD_E_3V3: U1.9 (LCD_E_3V3), U6.4 (LCD_E_3V3)
LCD_FB: RLCD1.2 (LCD_FB), RLCD2.1 (LCD_FB), U5.1 (LCD_FB)
LCD_POWER_EN: RLCDEN1.1 (LCD_POWER_EN), U1.7 (LCD_POWER_EN), U5.2 (LCD_POWER_EN)
LCD_RS: J3.4 (LCD_RS), U6.21 (LCD_RS)
LCD_RS_3V3: U1.8 (LCD_RS_3V3), U6.3 (LCD_RS_3V3)
LCD_SW: LLCD1.2 (LCD_SW), U5.5 (LCD_SW)
LCD_VO: J3.3 (LCD_VO), RVO1.2 (LCD_VO), RVO2.1 (LCD_VO)
LOCATE_N: D5.2 (LOCATE_N), RLOC1.2 (LOCATE_N), U1.4 (LOCATE_N)
LOCATE_RAW: D3.1 (LOCATE_RAW), D5.1 (LOCATE_RAW), SW1.1 (LOCATE_RAW), SW1.3 (LOCATE_RAW)
OFF_N: ROFF1.2 (OFF_N), SW2.1 (OFF_N), SW2.3 (OFF_N), U1.5 (OFF_N)
POWER_HOLD: Q2.1 (POWER_HOLD), RHOLD1.1 (POWER_HOLD), TP7.1, U1.6 (POWER_HOLD)
PWR_EN: D2.1 (PWR_EN), D4.1 (PWR_EN), REN1.1 (PWR_EN), U4.1 (PWR_EN)
PWR_START_GATE: D3.2 (PWR_START_GATE), Q1.1 (PWR_START_GATE), Q2.3 (PWR_START_GATE), RSTART1.2 (PWR_START_GATE)
PWR_START_OUT: D4.2 (PWR_START_OUT), Q1.3 (PWR_START_OUT)
QSPI_CSN: RBOOT1.1 (QSPI_CSN), U1.56 (QSPI_CSN), U2.1 (QSPI_CSN)
QSPI_SCLK: U1.52 (QSPI_SCLK), U2.6 (QSPI_SCLK)
QSPI_SD0: U1.53 (QSPI_SD0), U2.5 (QSPI_SD0)
QSPI_SD1: U1.55 (QSPI_SD1), U2.2 (QSPI_SD1)
QSPI_SD2: U1.54 (QSPI_SD2), U2.3 (QSPI_SD2)
QSPI_SD3: U1.51 (QSPI_SD3), U2.7 (QSPI_SD3)
RUN_N: CRESET1.1 (RUN_N), RRESET1.2 (RUN_N), SW4.1 (RUN_N), TP12.1, U1.26 (RUN_N)
SWCLK: TP11.1, U1.24 (SWCLK)
SWDIO: TP10.1, U1.25 (SWDIO)
SYS_RAW: CBBIN1.1 (SYS_RAW), CLCDIN1.1 (SYS_RAW), COUT1.1 (SYS_RAW), LLCD1.1 (SYS_RAW), Q1.2 (SYS_RAW), RSTART1.1 (SYS_RAW), TP3.1, U3.10 (SYS_RAW), U3.11 (SYS_RAW), U4.10 (SYS_RAW), U5.3 (SYS_RAW)
USB_DM: RUSB2.2 (USB_DM), U1.46 (USB_DM)
USB_DM_CONN: D1.2 (USB_DM_CONN), J1.A7 (USB_DM_CONN), J1.B7 (USB_DM_CONN), RUSB2.1 (USB_DM_CONN)
USB_DP: RUSB1.2 (USB_DP), U1.47 (USB_DP)
USB_DP_CONN: D1.1 (USB_DP_CONN), J1.A6 (USB_DP_CONN), J1.B6 (USB_DP_CONN), RUSB1.1 (USB_DP_CONN)
VBUS: CIN1.1 (VBUS), D2.2 (VBUS), F1.2 (VBUS), RVB1.1 (VBUS), TP1.1, U3.6 (VBUS), U3.13 (VBUS)
VBUS_PRESENT: RVB1.2 (VBUS_PRESENT), RVB2.1 (VBUS_PRESENT), U1.30 (VBUS_PRESENT)
VBUS_RAW: F1.1 (VBUS_RAW), J1.A4 (VBUS_RAW), J1.A9 (VBUS_RAW), J1.B4 (VBUS_RAW), J1.B9 (VBUS_RAW)
XIN: CX1.1 (XIN), U1.20 (XIN), X1.1 (XIN)
XOUT: RXTAL1.1 (XOUT), U1.21 (XOUT)
XOUT_XTAL: CX2.1 (XOUT_XTAL), RXTAL1.2 (XOUT_XTAL), X1.3 (XOUT_XTAL)

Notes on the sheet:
BQ24074 OUT is the sole SYS_RAW source. J1 VBUS_RAW passes through F1 to VBUS.
EXACT PAD-NUMBER NETLIST — all unassigned physical pads are explicit no-connects

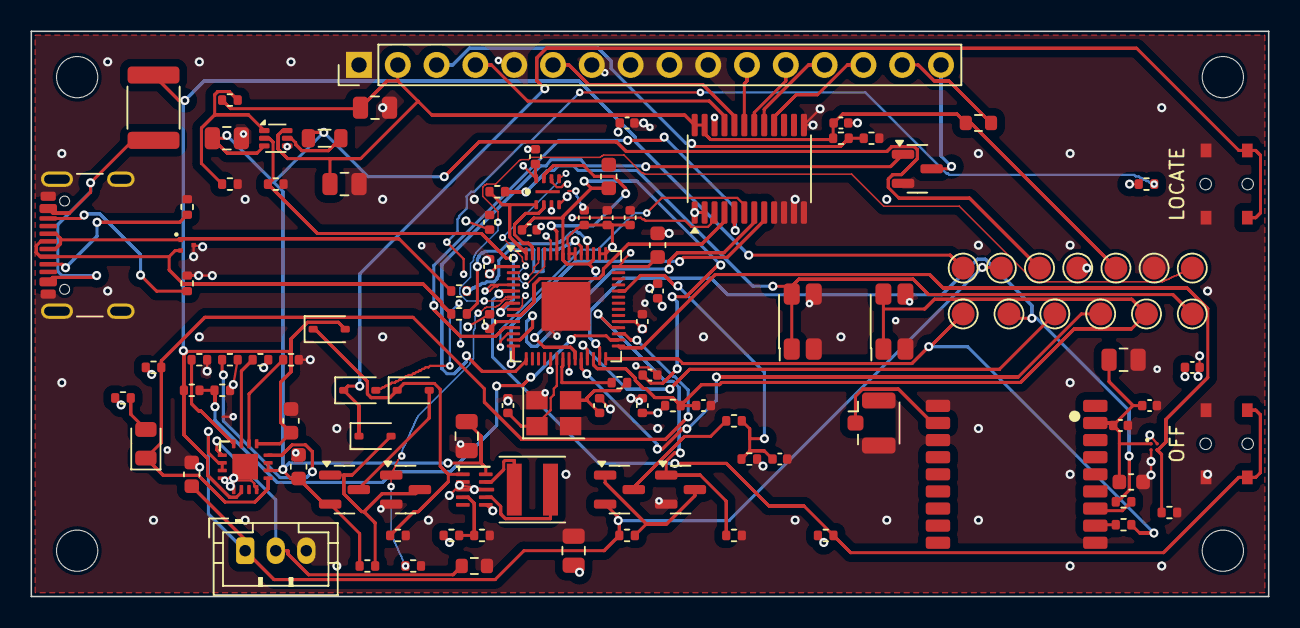
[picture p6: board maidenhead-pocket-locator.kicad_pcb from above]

Board: 4 copper layers, 81.0 x 37.0 mm, 117 parts (0 on the bottom side), 75 nets.

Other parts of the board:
H1, H2, H3, H4: M2.5; MountingHole_2.7mm_M2.5

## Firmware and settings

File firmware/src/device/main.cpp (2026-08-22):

// SPDX-License-Identifier: GPL-3.0-or-later
#include <array>
#include <cctype>
#include <cstdio>
#include <optional>
#include <string>
#include <string_view>

#include "hardware/watchdog.h"
#include "pico/stdlib.h"
#include "pico/stdio_usb.h"

#include "locator/maidenhead.h"
#include "pocket_locator/app/check_session.hpp"
#include "pocket_locator/board/battery.hpp"
#include "pocket_locator/board/bootloader.hpp"
#include "pocket_locator/board/buttons.hpp"
#include "pocket_locator/board/power.hpp"
#include "pocket_locator/config/config.hpp"
#include "pocket_locator/display/hd44780.hpp"
#include "pocket_locator/display/format.hpp"
#include "pocket_locator/gnss/uart_gnss.hpp"
#include "pocket_locator/storage/flash_config_store.hpp"
#include "pocket_locator/usb/protocol.hpp"

namespace {

[[nodiscard]] std::uint64_t now_ms() { return to_ms_since_boot(get_absolute_time()); }

[[nodiscard]] pocket_locator::app::SessionSettings session_settings(const pocket_locator::config::Settings& config) {
    return {
        .gnss_mode = config.gnss_mode,
        .hold_ms = 1'000,
        .factory_reset_hold_ms = 5'000,
        .acquisition_timeout_ms = config.acquisition_timeout_ms,
        .dim_deadline_ms = config.dim_deadline_ms,
        .shutdown_deadline_ms = config.shutdown_deadline_ms,
        .no_gps_message_ms = 3'000,
        .tracking_render_interval_ms = config.tracking_render_interval_ms,
    };
}

[[nodiscard]] const char* gnss_mode_name(pocket_locator::app::GnssMode mode) {
    return mode == pocket_locator::app::GnssMode::Tracking ? "tracking" : "single_fix";
}

[[nodiscard]] bool session_is_active(pocket_locator::app::State state) {
    using pocket_locator::app::State;
    return state == State::Acquiring || state == State::DisplayFix || state == State::Dimmed ||
           state == State::NoGps || state == State::FactoryReset;
}

[[nodiscard]] const char* date_format_name(pocket_locator::config::DateFormat format) {
    using pocket_locator::config::DateFormat;
    switch (format) {
        case DateFormat::DdMm: return "DD/MM";
        case DateFormat::MmDd: return "MM/DD";
        case DateFormat::DdMmm: return "DDMMM";
        case DateFormat::YyyyMmDd: return "YYYY-MM-DD";
    }
    return "DD/MM";
}

[[nodiscard]] std::string blocks_json(const std::vector<pocket_locator::config::DisplayBlock>& blocks) {
    using pocket_locator::config::DisplayBlockKind;
    std::string result{"["};
    for (std::size_t i = 0; i < blocks.size(); ++i) {
        if (i != 0U) result += ',';
        const auto& block = blocks[i];
        const char* kind = block.kind == DisplayBlockKind::Battery ? "battery" : block.kind == DisplayBlockKind::Time ? "time" :
                           block.kind == DisplayBlockKind::Date ? "date" : block.kind == DisplayBlockKind::Text ? "text" :
                           block.kind == DisplayBlockKind::Space ? "space" : "separator";
        result += "{\"kind\":\"";
        result += kind;
        result += "\"";
        if (!block.value.empty()) {
            std::string escaped;
            escaped.reserve(block.value.size());
            for (const char c : block.value) { if (c == '"' || c == '\\') escaped.push_back('\\'); escaped.push_back(c); }
            result += ",\"value\":\"" + escaped + "\"";
        }
        result += '}';
    }
    return result + ']';
}

[[nodiscard]] std::string config_json(const pocket_locator::config::Settings& config) {
    return "{\"schema_version\":" + std::to_string(config.schema_version) +
           ",\"top_template\":\"GRID: {grid6}\",\"bottom_blocks\":" + blocks_json(config.bottom_blocks) + ",\"timezone\":\"" +
           config.named_time_zone + "\",\"clock_24h\":" + (config.clock_24h ? "true" : "false") +
           ",\"show_seconds\":" + (config.show_seconds ? "true" : "false") + ",\"date_format\":\"" + date_format_name(config.date_format) + "\",\"gnss_mode\":\"" +
           gnss_mode_name(config.gnss_mode) + "\",\"tracking_interval_seconds\":" +
           std::to_string(config.tracking_render_interval_ms / 1000U) +
           ",\"acquisition_timeout_seconds\":" + std::to_string(config.acquisition_timeout_ms / 1000U) +
           ",\"dim_deadline_seconds\":" + std::to_string(config.dim_deadline_ms / 1000U) +
           ",\"shutdown_deadline_seconds\":" + std::to_string(config.shutdown_deadline_ms / 1000U) +
           ",\"normal_brightness_percent\":" + std::to_string(config.normal_brightness) +
           ",\"dim_brightness_percent\":" + std::to_string(config.dim_brightness) + "}";
}

void response(std::string_view request_id, std::string_view data) {
    std::printf("{\"request_id\":\"%.*s\",\"ok\":true,\"data\":%.*s}\n", static_cast<int>(request_id.size()), request_id.data(),
                static_cast<int>(data.size()), data.data());
}

[[nodiscard]] std::optional<std::string> json_string(std::string_view json, std::string_view key) {
    const std::string needle = "\"" + std::string(key) + "\"";
    const auto field = json.find(needle);
    if (field == std::string_view::npos) return std::nullopt;
    const auto colon = json.find(':', field + needle.size());
    if (colon == std::string_view::npos) return std::nullopt;
    const auto first_quote = json.find('"', colon + 1U);
    if (first_quote == std::string_view::npos) return std::nullopt;
    std::string result;
    bool escaping = false;
    for (std::size_t i = first_quote + 1U; i < json.size(); ++i) {
        const char c = json[i];
        if (escaping) {
            if (c != '"' && c != '\\' && c != '/') return std::nullopt;
            result.push_back(c); escaping = false; continue;
        }
        if (c == '\\') { escaping = true; continue; }
        if (c == '"') return result;
        if (static_cast<unsigned char>(c) < 0x20U) return std::nullopt;
        result.push_back(c);
    }
    return std::nullopt;
}

[[nodiscard]] std::optional<std::uint32_t> json_unsigned(std::string_view json, std::string_view key) {
    const std::string needle = "\"" + std::string(key) + "\"";
    const auto field = json.find(needle);
    if (field == std::string_view::npos) return std::nullopt;
    const auto colon = json.find(':', field + needle.size());
    if (colon == std::string_view::npos) return std::nullopt;
    std::size_t begin = colon + 1U;
    while (begin < json.size() && (json[begin] == ' ' || json[begin] == '\t')) ++begin;
    std::uint32_t value = 0;
    std::size_t index = begin;
    while (index < json.size() && json[index] >= '0' && json[index] <= '9') {
        const std::uint32_t digit = static_cast<std::uint32_t>(json[index] - '0');
        if (value > (UINT32_MAX - digit) / 10U) return std::nullopt;
        value = value * 10U + digit;
        ++index;
    }
    if (index == begin) return std::nullopt;
    while (index < json.size() && std::isspace(static_cast<unsigned char>(json[index])) != 0) ++index;
    return index == json.size() || json[index] == ',' || json[index] == '}'
               ? std::optional<std::uint32_t>(value)
               : std::nullopt;
}

[[nodiscard]] std::optional<bool> json_bool(std::string_view json, std::string_view key) {
    const std::string needle = "\"" + std::string(key) + "\"";
    const auto field = json.find(needle);
    if (field == std::string_view::npos) return std::nullopt;
    const auto colon = json.find(':', field + needle.size());
    if (colon == std::string_view::npos) return std::nullopt;
    auto begin = colon + 1U;
    while (begin < json.size() && (json[begin] == ' ' || json[begin] == '\t' ||
                                   json[begin] == '\r' || json[begin] == '\n')) ++begin;
    const auto value = json.substr(begin);
    const auto token_matches = [&](std::string_view token) {
        if (!value.starts_with(token)) return false;
        auto end = token.size();
        while (end < value.size() && std::isspace(static_cast<unsigned char>(value[end])) != 0) ++end;
        return end == value.size() || value[end] == ',' || value[end] == '}';
    };
    if (token_matches("true")) return true;
    if (token_matches("false")) return false;
    return std::nullopt;
}

[[nodiscard]] std::optional<pocket_locator::config::DisplayBlockKind> block_kind(std::string_view value) {
    using pocket_locator::config::DisplayBlockKind;
    if (value == "battery") return DisplayBlockKind::Battery;
    if (value == "time") return DisplayBlockKind::Time;
    if (value == "date") return DisplayBlockKind::Date;
    if (value == "text") return DisplayBlockKind::Text;
    if (value == "space") return DisplayBlockKind::Space;
    if (value == "separator") return DisplayBlockKind::Separator;
    return std::nullopt;
}

[[nodiscard]] std::optional<std::size_t> matching_delimiter(std::string_view text, std::size_t open, char opening, char closing) {
    if (open >= text.size() || text[open] != opening) return std::nullopt;
    int depth = 0; bool in_string = false; bool escaping = false;
    for (std::size_t i = open; i < text.size(); ++i) {
        const char c = text[i];
        if (in_string) {
            if (escaping) escaping = false;
            else if (c == '\\') escaping = true;
            else if (c == '"') in_string = false;
            continue;
        }
        if (c == '"') in_string = true;
        else if (c == opening) ++depth;
        else if (c == closing && --depth == 0) return i;
    }
    return std::nullopt;
}

[[nodiscard]] std::optional<std::vector<pocket_locator::config::DisplayBlock>> parse_blocks(std::string_view json) {
    const auto field = json.find("\"bottom_blocks\"");
    if (field == std::string_view::npos) return std::nullopt;
    const auto open = json.find('[', field);
    const auto close = matching_delimiter(json, open, '[', ']');
    if (open == std::string_view::npos || !close) return std::nullopt;
    std::vector<pocket_locator::config::DisplayBlock> blocks;
    std::size_t cursor = open + 1U;
    while (cursor < *close) {
        while (cursor < *close && std::isspace(static_cast<unsigned char>(json[cursor])) != 0) ++cursor;
        if (cursor == *close) break;
        if (json[cursor] != '{') return std::nullopt;
        const auto begin = cursor;
        const auto end = matching_delimiter(json, begin, '{', '}');
        if (!end || *end > *close) return std::nullopt;
        const auto object = json.substr(begin, *end - begin + 1U);
        static constexpr std::array<std::string_view, 2> kBlockKeys{"kind", "value"};
        if (!pocket_locator::usb::object_has_exact_keys(object, kBlockKeys)) return std::nullopt;
        const auto kind = json_string(object, "kind");
        const auto value = json_string(object, "value");
        if (!kind || !block_kind(*kind) || !value) return std::nullopt;
        blocks.push_back({*block_kind(*kind), *value});
        cursor = *end + 1U;
        while (cursor < *close && std::isspace(static_cast<unsigned char>(json[cursor])) != 0) ++cursor;
        if (cursor < *close && json[cursor++] != ',') return std::nullopt;
    }
    return blocks.empty() ? std::nullopt : std::optional(blocks);
}

[[nodiscard]] std::optional<std::int64_t> json_signed64(std::string_view json, std::string_view key) {
    const std::string needle = "\"" + std::string(key) + "\"";
    const auto field = json.find(needle);
    if (field == std::string_view::npos) return std::nullopt;
    const auto colon = json.find(':', field + needle.size());
    if (colon == std::string_view::npos) return std::nullopt;
    std::size_t i = colon + 1U; while (i < json.size() && (json[i] == ' ' || json[i] == '\t')) ++i;
    bool negative = i < json.size() && json[i] == '-'; if (negative) ++i;
    std::int64_t value = 0; const auto begin = i;
    while (i < json.size() && json[i] >= '0' && json[i] <= '9') { if (value > (INT64_MAX - (json[i] - '0')) / 10) return std::nullopt; value = value * 10 + (json[i++] - '0'); }
    if (i == begin) return std::nullopt;
    while (i < json.size() && std::isspace(static_cast<unsigned char>(json[i])) != 0) ++i;
    if (i != json.size() && json[i] != ',' && json[i] != '}') return std::nullopt;
    return negative ? -value : value;
}

[[nodiscard]] std::optional<std::string_view> json_object(std::string_view json, std::string_view key) {
    const std::string needle = "\"" + std::string(key) + "\"";
    const auto field = json.find(needle);
    if (field == std::string_view::npos) return std::nullopt;
    const auto open = json.find('{', field + needle.size());
    if (open == std::string_view::npos) return std::nullopt;
    const auto close = matching_delimiter(json, open, '{', '}');
    return close ? std::optional(json.substr(open, *close - open + 1U)) : std::nullopt;
}
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
int main() {
    using namespace pocket_locator;
    board::PowerHold power;
    power.init();
    bool usb_stdio_active = false;
    if (power.usb_present()) {
        usb_stdio_active = stdio_usb_init();
    }
    board::Buttons buttons;
    buttons.init();
    board::BatteryAdc battery;
    battery.init();
    display::Hd44780 lcd;
    lcd.init();
    gnss::UartGnss gnss;
    gnss.init();
    storage::FlashConfigStore flash;
    auto loaded = flash.load();
    auto settings = loaded.settings;
    app::CheckSession session(session_settings(settings));
    usb::NdjsonFramer framer;
    app::State last_state = app::State::Off;
    std::string last_grid;
    std::string last_bottom;
    std::optional<locator::CurrentFix> latest_fix;
    std::uint64_t latest_fix_at_ms = 0;
    bool timezone_refresh_required = false;
    bool factory_reset_failed = false;
    bool last_gnss = false;
    bool power_held = false;
    board::BatteryReading battery_reading{};
    bool battery_read_pending = false;
    std::uint64_t battery_read_started_ms = 0;
    std::uint64_t last_battery_read_ms = 0;
    constexpr std::uint64_t kBatterySampleIntervalMs = 1'000;
    constexpr std::uint64_t kBatterySettleMs =
        (board::kBatteryDividerSettleUs + 999U) / 1'000U;
    watchdog_enable(8'000, true);

    while (true) {
        const auto now = now_ms();
        watchdog_update();
        const bool usb_present = power.usb_present();
        if (usb_present != usb_stdio_active) {
            if (usb_present) {
                usb_stdio_active = stdio_usb_init();
            } else {
                (void)stdio_usb_deinit();
                usb_stdio_active = false;
            }
        }
        auto update = session.set_usb_present(usb_present, now);
        const auto merge = [](app::Update& target, const app::Update& next) {
            target.display_changed = target.display_changed || next.display_changed;
            target.power_released = target.power_released || next.power_released;
            target.factory_reset_requested = target.factory_reset_requested || next.factory_reset_requested;
        };
        board::ButtonEvent button{};
        while (buttons.poll(now, button)) {
            merge(update, button.down ? session.button_down(button.button, button.pressed_at_ms) : session.button_up(button.button, now));
        }
        merge(update, session.tick(now));
        if (session.state() == app::State::Acquiring && !power_held) {
            power.assert_hold();
            power_held = true;
        }
        if (session.gnss_is_active() != last_gnss) {
            gnss.set_enabled(session.gnss_is_active());
            last_gnss = session.gnss_is_active();
        }
        const auto gnss_update = gnss.poll();
        if (gnss_update.invalid_fix && !gnss_update.invalid_after_fix) {
            merge(update, session.invalid_fix(now));
        }
        if (const auto& fix = gnss_update.fix; fix.has_value()) {
            latest_fix = fix;
            latest_fix_at_ms = now;
            if (const auto grid = locator::maidenhead_6(fix->position.latitude_degrees, fix->position.longitude_degrees); grid) {
                merge(update, session.valid_fix(*grid, now));
            }
        }
        if (gnss_update.invalid_after_fix) {
            merge(update, session.invalid_fix(now));
        }
        if (session.state() == app::State::UsbIdle || session.state() == app::State::Off || session.state() == app::State::PressCheck) {
            latest_fix.reset();
        }

        for (int character = getchar_timeout_us(0); character != PICO_ERROR_TIMEOUT; character = getchar_timeout_us(0)) {
            const auto frame = framer.push(static_cast<char>(character));
            if (!frame) continue;
            if (frame->kind == usb::FrameKind::TooLarge) {
                std::printf("%s", usb::error_response("", usb::ErrorCode::MessageTooLarge).c_str());
                continue;
            }
            const auto request = usb::parse_request(frame->payload);
            if (!request.request) {
                std::printf("%s", usb::error_response("", *request.error).c_str());
                continue;
            }
            const auto& request_value = *request.request;
            if (request_value.protocol_version != usb::kProtocolVersion) {
                std::printf("%s", usb::error_response(request_value.request_id, usb::ErrorCode::UnsupportedProtocol).c_str());
                continue;
            }
            switch (request_value.command) {
                case usb::Command::Hello:
                    response(request_value.request_id, "{\"protocol_version\":1,\"device\":\"pocket-locator\"}"); break;
                case usb::Command::GetInfo:
                    response(request_value.request_id, "{\"firmware_version\":\"0.1.0\",\"hardware_revision\":\"rev-a\"}"); break;
                case usb::Command::GetConfig:
                    response(request_value.request_id, config_json(settings)); break;
                case usb::Command::GetDiagnostics: {
                    const bool session_active = session_is_active(session.state());
                    std::string diagnostics =
                             "{\"config_schema_version\":" + std::to_string(settings.schema_version) +
                                 ",\"config_crc_healthy\":" + std::string(loaded.crc_healthy ? "true" : "false") +
                                 ",\"config_source\":\"" +
                                 (loaded.used_factory_defaults ? "safe_factory_defaults" : "flash") + "\"" +
                                 ",\"battery_adc\":" + std::to_string(battery_reading.raw) + ",\"battery_level\":" +
                                 std::to_string(battery_reading.percent) + ",\"battery_millivolts\":" + std::to_string(battery_reading.millivolts) +
                                 ",\"onboard_temperature_celsius\":" + std::to_string(battery_reading.temperature_centi_celsius / 100) +
                                 ",\"usb_present\":" +
                                 std::string(power.usb_present() ? "true" : "false") + ",\"gnss_state\":\"" +
                                 (gnss.enabled() ? "active" : "off") + "\",\"timezone_refresh_required\":" +
                                 std::string(timezone_refresh_required ? "true" : "false") + ",\"charger_active\":" +
                                 std::string(power.charger_active() ? "true" : "false") + ",\"gnss_fix_quality\":" +
                                 std::to_string(session_active && latest_fix ? latest_fix->fix_quality : 0U) + ",\"satellites_used\":" +
                                 std::to_string(session_active && latest_fix ? latest_fix->satellites_used : 0U);
                    if (session_active && latest_fix) {
                        diagnostics += ",\"latest_coordinates\":{\"latitude\":" + std::to_string(latest_fix->position.latitude_degrees) +
                                       ",\"longitude\":" + std::to_string(latest_fix->position.longitude_degrees) + "}";
                    }
                    response(request_value.request_id, diagnostics + "}");
                    break;
                }
                case usb::Command::ValidateConfig:
                case usb::Command::SetConfig: {
                    static constexpr std::array<std::string_view, 4> kSetRequestKeys{
                        "protocol_version", "request_id", "command", "config"};
                    if (!usb::object_has_exact_keys(request_value.raw_json, kSetRequestKeys)) {
                        std::printf("%s", usb::error_response(request_value.request_id, usb::ErrorCode::InvalidField).c_str());
                        break;
                    }
                    const auto config_object = json_object(request_value.raw_json, "config");
                    const auto candidate = config_object ? config_from_request(*config_object) : std::nullopt;
                    if (!candidate) {
                        std::printf("%s", usb::error_response(request_value.request_id, usb::ErrorCode::InvalidField).c_str());
                        break;
                    }
                    if (request_value.command == usb::Command::SetConfig) {
                        if (session_is_active(session.state())) {
                            std::printf("%s", usb::error_response(request_value.request_id, usb::ErrorCode::Busy).c_str());
                            break;
                        }
                        if (flash.write(*candidate) != config::ValidationError::None) {
                            std::printf("%s", usb::error_response(request_value.request_id, usb::ErrorCode::StorageError).c_str());
                            break;
                        }
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

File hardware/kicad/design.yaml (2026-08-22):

# SPDX-License-Identifier: CERN-OHL-S-2.0
# Connected Revision-A electrical contract. Purchased-part drawings and bench
# results remain mandatory release gates.
project: maidenhead-pocket-locator
revision: A-electrical
board:
  width_mm: 81.0
  height_mm: 37.0
  layers: 4
  thickness_mm: 1.6
  stackup: "F.Cu signal/power, In1 solid GND, In2 3V3 power with LCD_RS_3V3 under 7 mm, LOCATE_N under 4 mm, and QSPI_SCLK/QSPI_SD2 under 6 mm, B.Cu signal/GND; USB and RF stay outer-layer; freeze vendor dielectric and recalculate USB/RF impedance before release"
power_architecture:
  charger_source: "BQ24074 OUT is the sole SYS_RAW source; BAT never bypasses OUT"
  system_regulator: "TPS63802DLAR adjustable buck-boost, 3.3 V, 0.47 uH, 511k/91k feedback"
  start_logic: "TPS63802 EN is diode-OR of USB VBUS and Q1 signal-PMOS output"
  locate_start: "SW1 pulls isolated LOCATE_RAW low; D3 starts Q1 and D5 reports LOCATE_N without an off-state 3V3-to-latch path"
  usb_idle: "VBUS forces 3V3 only; GPIO5 LCD_POWER_EN and GPIO18 GNSS_EN default low"
  off_state: "TPS63802 shutdown; charger/protected cell and signal latch remain BAT-connected"
nets:
  power: [VBUS, BAT, SYS_RAW, PWR_EN, 3V3, 1V1, 3V3_GNSS, 5V_LCD, GND]
  usb: [VBUS_RAW, USB_DP_CONN, USB_DM_CONN, USB_DP, USB_DM, CC1, CC2]
  control: [LOCATE_N, OFF_N, POWER_HOLD, LCD_POWER_EN, GNSS_EN, BAT_SENSE_EN, VBUS_PRESENT, CHG_N]
  gnss: [GNSS_TX, GNSS_RX, GNSS_PPS, GNSS_RF_50R]
  lcd: [LCD_RS, LCD_E, LCD_D4, LCD_D5, LCD_D6, LCD_D7, LCD_BL_A, LCD_BL_K, BL_PWM]
components:
  - {ref: U1, mpn: RP2040, package: "QFN-56 7x7", role: MCU}
  - {ref: U2, mpn: W25Q16JVUXIQ, package: "USON-8 2x3", role: boot_flash}
  - {ref: U3, mpn: BQ24074RGTR, package: "VQFN-16 3x3", role: power_path_charger}
  - {ref: U4, mpn: TPS63802DLAR, package: "VSON-HR-10 3x2", role: 3v3_buck_boost}
  - {ref: U5, mpn: TPS61023DRLR, package: "SOT-563-6", role: lcd_boost}
  - {ref: U6, mpn: SN74LVC8T245PWR, package: TSSOP-24, role: lcd_level_shift}
  - {ref: U7, mpn: Ai-Thinker-GP-02, package: "SMD-18 9.9x10.3 mm P1.12 manufacturer land", role: GNSS}
  - {ref: U8, mpn: TPS22916BYFPR, package: "YFP DSBGA-4 0.78x0.78 mm P0.4", role: gnss_load_switch}
  - {ref: Q1, mpn: DMP3098L-7, role: signal_only_start_switch}
  - {ref: Q2, mpn: DMN2050L-7, role: power_hold_gate_pull_down}
  - {ref: Q3, mpn: DMN2050L-7, role: lcd_backlight_pwm}
  - {ref: Q4, mpn: DMP3098L-7, role: battery_divider_high_side}
  - {ref: Q5, mpn: DMN2050L-7, role: battery_divider_gate}
  - {ref: J1, mpn: GCT_USB4105-GF-A, role: USB-C_device}
  - {ref: J2, mpn: "B3B-PH-K-S(LF)(SN)", role: protected_cell_NTC}
  - {ref: J3, mpn: "61301611121", role: lcd_header}
  - {ref: J4, mpn: "20449-001E", role: GNSS_uFL}
firmware_contract:
  GPIO2: LOCATE_N
  GPIO3: OFF_N
  GPIO4: POWER_HOLD
  GPIO5: LCD_POWER_EN
  GPIO6: LCD_RS_3V3
  GPIO7: LCD_E_3V3
  GPIO8: LCD_D4_3V3
  GPIO9: LCD_D5_3V3
  GPIO10: LCD_D6_3V3
  GPIO11: LCD_D7_3V3
  GPIO12: BL_PWM
  GPIO16: GNSS_RX
  GPIO17: GNSS_TX
  GPIO18: GNSS_EN
  GPIO19: VBUS_PRESENT
  GPIO20: CHG_N
  GPIO21: BAT_SENSE_EN
  GPIO26_ADC0: BAT_ADC
release_blockers:
  - "Verify every footprint and pad number against the ordered manufacturer drawing."
  - "Verify the GP-02 and TPS22916 footprints against the ordered lot/package markings before assembly release."
  - "Calculate GNSS 50-ohm CPWG width/clearance from the exact ordered stack-up."
  - "Run KiCad GUI ERC/DRC and archive zero-unreviewed-error reports."
  - "Measure LCD current, charge/NTC, shutdown current, RF and thermal behavior."

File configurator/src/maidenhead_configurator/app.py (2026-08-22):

# SPDX-License-Identifier: GPL-3.0-or-later
from __future__ import annotations

import json
import tkinter as tk
from copy import deepcopy
from datetime import datetime
from pathlib import Path
from tkinter import filedialog, messagebox, simpledialog, ttk
from zoneinfo import ZoneInfo, available_timezones

from .firmware import FirmwareUpdater, find_rp2040_volumes
from .models import (
    DATE_FORMATS,
    GNSS_MODES,
    ConfigError,
    DeviceConfig,
    DisplayBlock,
    render_bottom,
    reorder_blocks,
)
from .profiles import Profile, load_profile, profile_diff, save_profile
from .protocol import Client, ProtocolError
from .serial_transport import NdjsonSerialTransport, SerialDevice, discover_devices
from .simulator import SimulatedTransport
from .timezone_table import generate_timezone_table
from .uf2 import inspect_uf2


class ConfiguratorApp(tk.Tk):
    """Desktop editor. Changes are never written until the user presses Apply."""

    def __init__(self, client: Client | None = None) -> None:
        super().__init__()
        self.title("Maidenhead Pocket Locator")
        self.minsize(760, 560)
        self.client = client or Client(SimulatedTransport())
        self._serial_transport: NdjsonSerialTransport | None = None
        self._known_devices: dict[str, SerialDevice] = {}
        self._connected_device: SerialDevice | None = None
        self.config_model = DeviceConfig.from_dict(self.client.request("get_config"))
        self.status = tk.StringVar(value="Connected to simulated device")
        self.preview = tk.StringVar()
        self.connection_choice = tk.StringVar(value="Simulator")
        self._drag_block_index: int | None = None
        self._build()
        self._load_model_into_widgets()
        self._refresh_preview()

    def destroy(self) -> None:
        if self._serial_transport:
            self._serial_transport.close()
        super().destroy()

    def _build(self) -> None:
        header = ttk.Frame(self, padding=(8, 8, 8, 4))
        header.pack(fill="x")
        ttk.Label(header, text="Device:").pack(side="left")
        self.device_combo = ttk.Combobox(
            header, textvariable=self.connection_choice, state="readonly", width=44
        )
        self.device_combo.pack(side="left", padx=6)
        ttk.Button(header, text="Refresh USB", command=self._refresh_usb).pack(side="left")
        ttk.Button(header, text="Connect", command=self._connect).pack(side="left", padx=6)
        ttk.Label(self, textvariable=self.status, padding=(8, 4)).pack(fill="x")
        tabs = ttk.Notebook(self)
        tabs.pack(fill="both", expand=True, padx=8, pady=(0, 8))
        for name in (
            "Device",
            "Display builder",
            "Behavior",
            "Time",
            "Profiles",
            "Firmware",
            "Factory reset",
        ):
            frame = ttk.Frame(tabs, padding=16)
            tabs.add(frame, text=name)
            getattr(self, f"_build_{name.lower().replace(' ', '_')}")(frame)
        footer = ttk.Frame(self, padding=(8, 0, 8, 8))
        footer.pack(fill="x")
        ttk.Button(footer, text="Discard changes", command=self._reload).pack(side="left")
        ttk.Button(footer, text="Validate and apply", command=self._apply).pack(side="right")

    def _refresh_usb(self) -> None:
        try:
            devices = discover_devices()
            self._known_devices = {device.label: device for device in devices}
            values = ["Simulator", *(device.label for device in devices)]
            self.device_combo["values"] = values
            if self.connection_choice.get() not in values:
                self.connection_choice.set(values[0])
            self.status.set(f"Found {len(devices)} compatible USB device(s)")
        except ProtocolError as exc:
            self._show_error("USB discovery", exc)

    def _connect(self) -> None:
        choice = self.connection_choice.get()
        transport: NdjsonSerialTransport | None = None
        try:
            if choice == "Simulator":
                client = Client(SimulatedTransport())
                selected_device = None
            else:
                selected_device = self._known_devices.get(choice)
                if selected_device is None:
                    raise ProtocolError(
                        "device_selection_stale",
                        "refresh USB and explicitly select the target device",
                    )
                port = selected_device.port
                transport = NdjsonSerialTransport(port)
                client = Client(transport)
                hello = client.request("hello")
                if not isinstance(hello, dict) or hello.get("protocol_version") != 1:
                    transport.close()
                    raise ProtocolError("unsupported_protocol", "device protocol is not compatible")
            model = DeviceConfig.from_dict(client.request("get_config"))
        except (ProtocolError, ConfigError) as exc:
            if transport:
                transport.close()
            self._show_error("Connection failed", exc)
            return
        if self._serial_transport:
            self._serial_transport.close()
        self._serial_transport, self.client, self.config_model = transport, client, model
        self._connected_device = selected_device
        self._load_model_into_widgets()
        self._refresh_preview()
        self.status.set(f"Connected to {choice}")

    def _build_device(self, frame: ttk.Frame) -> None:
        self.device_info = tk.StringVar(
            value="Select Refresh USB then Connect to use a physical device."
        )
        ttk.Label(
            frame, textvariable=self.device_info, justify="left", font=("TkFixedFont", 10)
        ).pack(anchor="w")
        ttk.Button(
            frame, text="Refresh device information", command=self._refresh_device_info
        ).pack(anchor="w", pady=12)

    def _refresh_device_info(self) -> None:
        try:
            info = self.client.request("get_info")
            diagnostics = self.client.request("get_diagnostics")
            self.device_info.set(
                json.dumps({"info": info, "diagnostics": diagnostics}, indent=2, sort_keys=True)
            )
        except ProtocolError as exc:
            self._show_error("Device information", exc)
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

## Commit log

2026-08-19 Add initial device plan
2026-08-19 Build full pocket locator source package
    [BOM_REV_A_ENGINEERING.csv, PASSIVES_REV_A_ENGINEERING.csv, base.stl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]
2026-08-22 Finish pocket locator project sources
    [BOM_REV_A_ENGINEERING.csv, PASSIVES_REV_A_ENGINEERING.csv, base.stl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]
2026-08-22 Install KiCad footprint libraries in CI

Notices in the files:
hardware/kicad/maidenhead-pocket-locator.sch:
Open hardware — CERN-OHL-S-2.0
